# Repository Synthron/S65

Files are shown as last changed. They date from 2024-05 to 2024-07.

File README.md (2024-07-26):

# S65xx Computer System

Yet another 8bit Retro Computer

Completely bloated, overkill and fully hackable!

## ToDo

- [x] Finish Hardware
- Software
  - [ ] WozMon
    - [x] Implement Serial IO
    - [x] Implement Input Buffer
    - [ ] extended for block write
  - [ ] Kernel Functions
    - [ ] General SysCalls
    - [ ] Hardware Drivers
  - [x] RAM-Kernel
  - [x] Basic
  - [x] EhBasic
  - [ ] File System
  - [ ] Operating System
- Hardware
  - [ ] order PCBs
  - [ ] order parts
  - [ ] solder together

## Hardware

- Modules
  - [x] Backplane Bus
  - [x] CPU
  - [x] ROM
  - [x] RAM
  - [x] Bank/IRQ
  - [x] LCD/IRQ
  - [x] SIO
  - [x] PIO
  - [x] User Ports
  - [x] IDE
  - [x] Simple-IDE
  - [x] CF
  - [x] SID
  - [x] Addr + RTC + Clock
  - [x] Prototyping Board
  - [x] LPT Interface
  - [x] MyCPU Graphics Unit Interface

## Software Brainstorm

- EhBasic
  - maybe Microsoft Basic? See Ben Eater
    - both in different banks
- WozMon Main Boot
- Serial Program Bootloader
- File System (FAT?)
- DOS-Like UI

boot routine:

- selftest
  - RAM Check
  - ROM Check + version
- Load Kernel functions to RAM
- Start Monitor

## Memory Map

General:

| Start | End  | Usage | Size |
|---|---|---|---|
| 0000  | 7FFF | RAM | 32.768 |
| 8000  | BEFF | RAM Banked | 16.128 |
| BF00  | BFFF | IO Space | 256 |
| C000  | FFFF | ROM Banked | 16.384 |

IO Space:

| Start | End  | Usage |Size|
|---|---|---|----|
| BF00  | BF07 | Bank & IRQ | 8  |
| BF08  | BF0F | TPI IDE | 8  |
| BF10  | BF12 | LPT | 2  |
| BF13  | BF14 | --- (LPT2) | 2  |
| BF14  | BF16 | MyCPU VGA | 3  |
| BF17  | BF1B | --- | 5  |
| BF1C  | BF1F | PIA LEDs | 4  |
| BF20  | BF2F | VIA 1 LCD IRQ | 16 |
| BF30  | BF3F | VIA 2 | 16 |
| BF40  | BF4F | VIA 3 | 16 |
| BF50  | BF53 | ACIA 1 | 4  |
| BF54  | BF57 | ACIA 2 | 4  |
| BF58  | BF5B | --- (ACIA 3)  | 4  |
| BF5C  | BF5F | --- (ACIA 4)  | 4  |
| BF60  | BF7F | SID 8580 | 32 |
| BF80  | BF87 | Simple IDE | 8  |
| BF88  | BF8F | CF Card | 8  |
| BF90  | BF9F | RTC | 16 |
| BFA0  | BFFF | --- | 96 |

## Interrupts

The TPI Chip for the memory banks also functions as a priority interrupt controller, providing 5 seperate interrupt lines.  
IRQ_0 is further divided into 8 lines for communication modules, giving an overall of 14 available IRQ-Lines.  

These are currently used as follows:

- IRQ -> TPI
  - IRQ_0 -> VIA0
    - IRQ_0.0 -> ACIA0
    - IRQ_0.1 -> ACIA1
    - IRQ_0.2 -> ACIA2
    - IRQ_0.3 -> ACIA3
    - IRQ_0.4 -> RTC
    - IRQ_0.5 -> ---
    - IRQ_0.6 -> ---
    - IRQ_0.7 -> ---
  - IRQ_1 -> VIA1
  - IRQ_2 -> VIA2
  - IRQ_3 -> ---
  - IRQ_4 -> ---
- NMI -> ---

Note that the NMI is connected to a push button on the bus board.

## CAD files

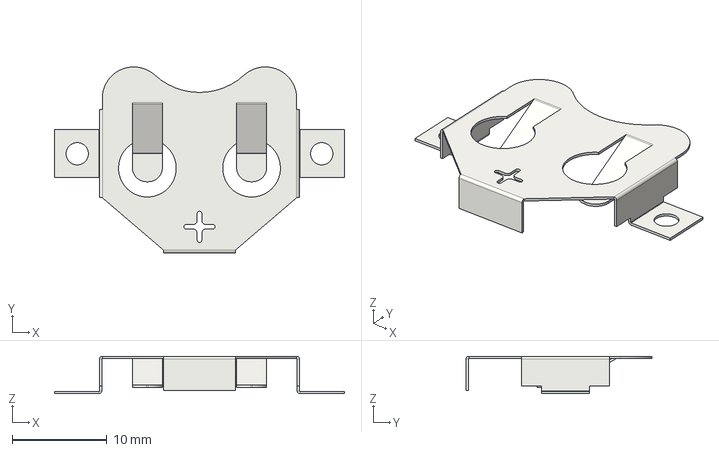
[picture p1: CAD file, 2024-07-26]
Hardware/modules/Address_Decode/BatteryHolder_Keystone_3002_1x2032.step
30.7 x 19.7 x 3.96 mm

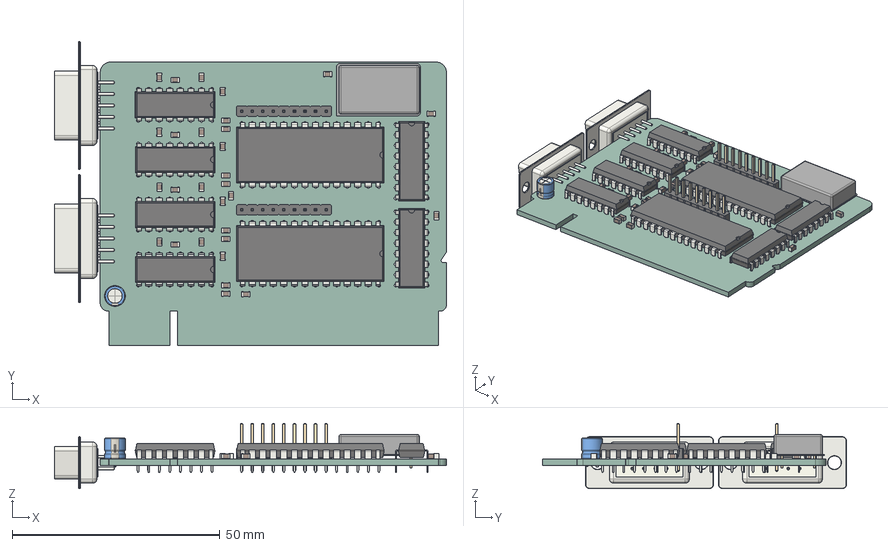
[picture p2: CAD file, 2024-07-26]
Hardware/modules/Bus_Card/modules_3d/ACIA2.step
94.3 x 73.1 x 15.7 mm
DIP-16_W7.62mm x 6
C_0805_2012Metric x 29
DSUB-9_Male_Vertical_P2.77x2.84mm x 2
DIP-28_W15.24mm x 2
Oscillator_DIP-14
CP_Radial_D50mm_P250mm
PinHeader_1x09_P254mm_Vertical x 2
ACIA2_PCB

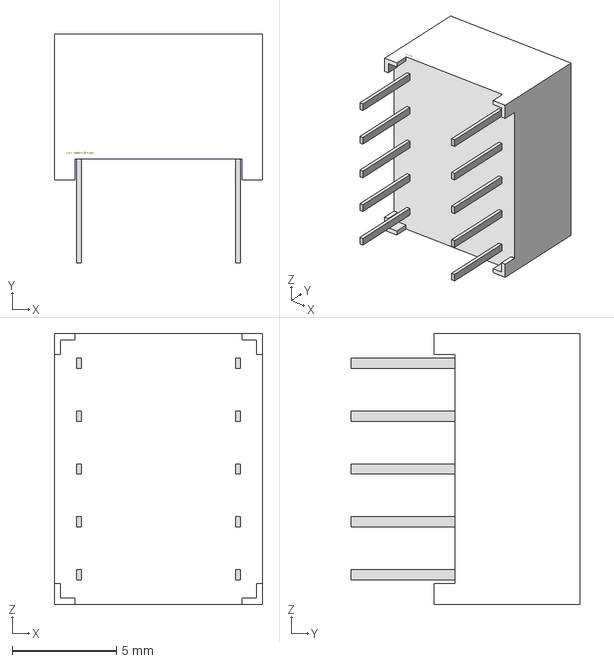
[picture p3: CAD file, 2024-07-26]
Hardware/modules/Bus_Card/Sx39-1xxxxx.step
10.0 x 11.0 x 13.0 mm

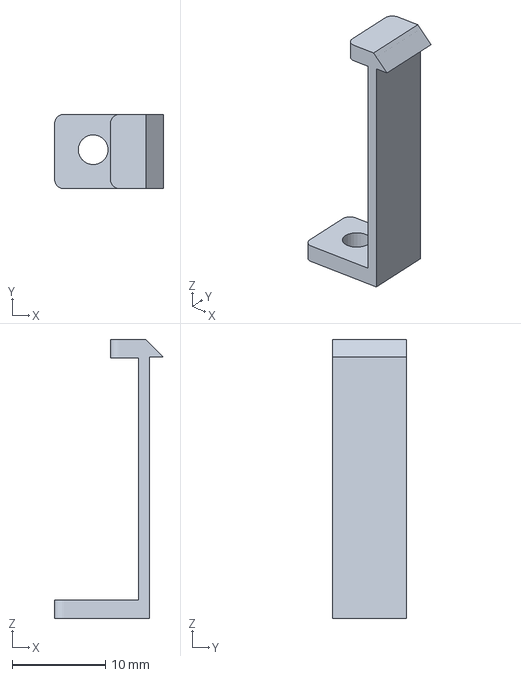
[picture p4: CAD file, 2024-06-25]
Hardware/PCB-Clamp/clamp-Clamp.3mf
11.7 x 8.00 x 30.0 mm

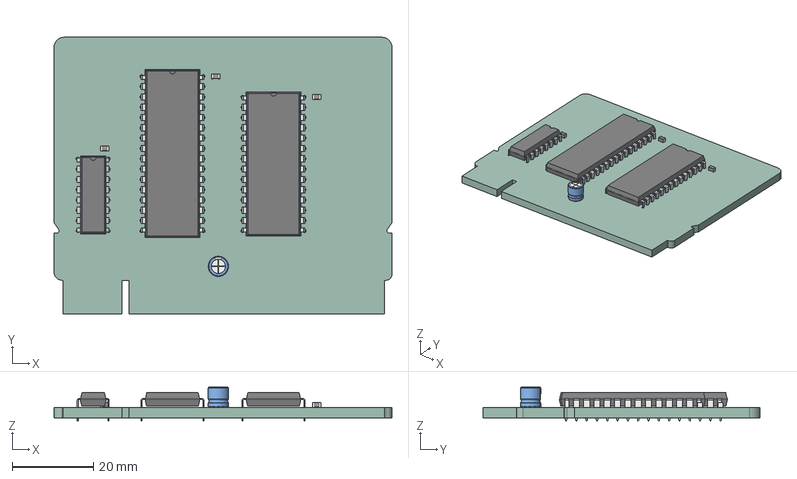
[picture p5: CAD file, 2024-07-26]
Hardware/modules/Bus_Card/modules_3d/RAM.step
83.3 x 68.2 x 8.30 mm
C_0805_2012Metric x 3
DIP-32_W15.24mm
DIP-28_W15.24mm
DIP-16_W7.62mm
CP_Radial_D50mm_P250mm
RAM_PCB

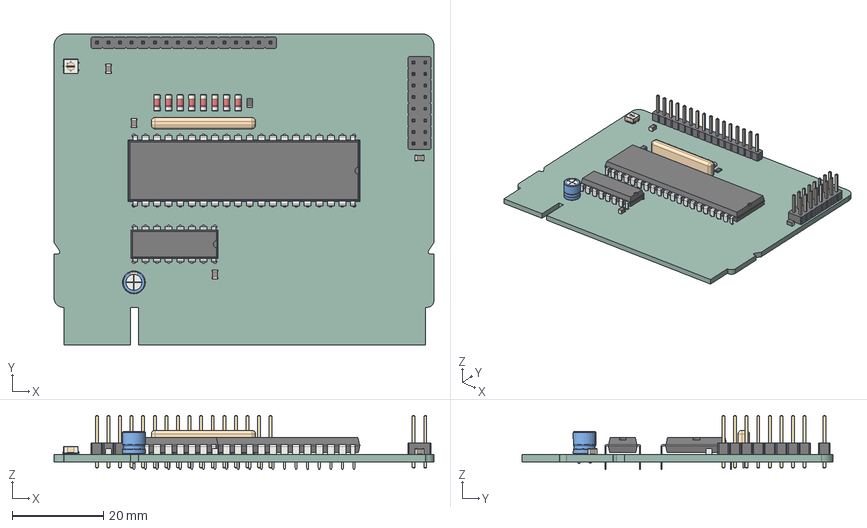
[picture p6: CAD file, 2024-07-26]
Hardware/modules/Bus_Card/modules_3d/LCD_IRQ.step
83.3 x 68.2 x 11.8 mm
Potentiometer_Bourns_3314J_Vertical
R_0805_2012Metric
D_MiniMELF_Standard x 8
C_0805_2012Metric x 4
PinHeader_2x08_P254mm_Vertical
DIP-40_W15.24mm
CP_Radial_D50mm_P250mm
PinHeader_1x16_P254mm_Vertical
DIP-16_W7.62mm
R_Array_SIP9
LCD_IRQ_PCB

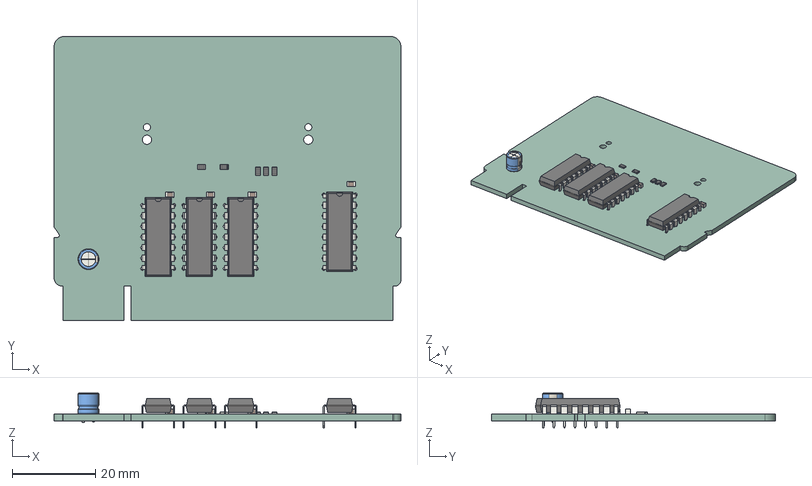
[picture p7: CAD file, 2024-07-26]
Hardware/modules/Bus_Card/modules_3d/CF.step
83.3 x 68.2 x 8.30 mm
R_0805_2012Metric x 5
C_0805_2012Metric x 4
DIP-14_W7.62mm x 3
DIP-16_W7.62mm
CP_Radial_D50mm_P250mm
CF_PCB

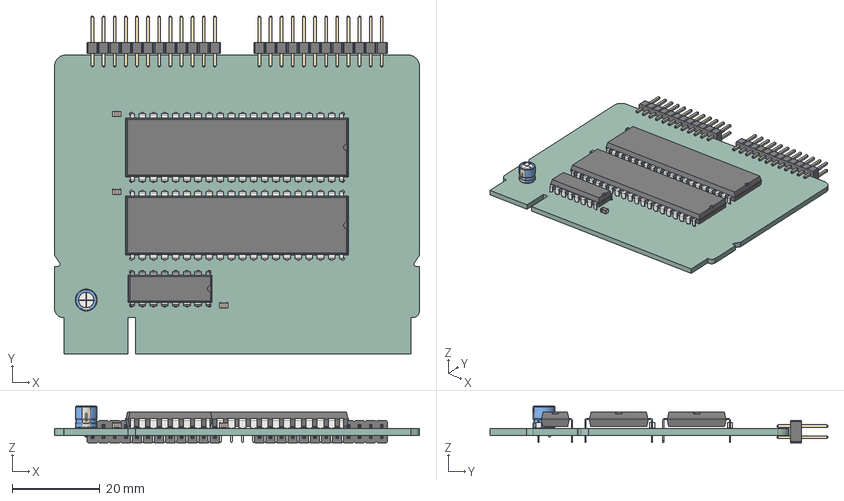
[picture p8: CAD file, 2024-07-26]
Hardware/modules/Bus_Card/modules_3d/VIAs.step
83.3 x 77.1 x 8.37 mm
C_0805_2012Metric x 3
DIP-40_W15.24mm x 2
DIP-16_W7.62mm
CP_Radial_D50mm_P250mm
PinHeader_2x12_P254mm_Vertical x 2
VIAs_PCB

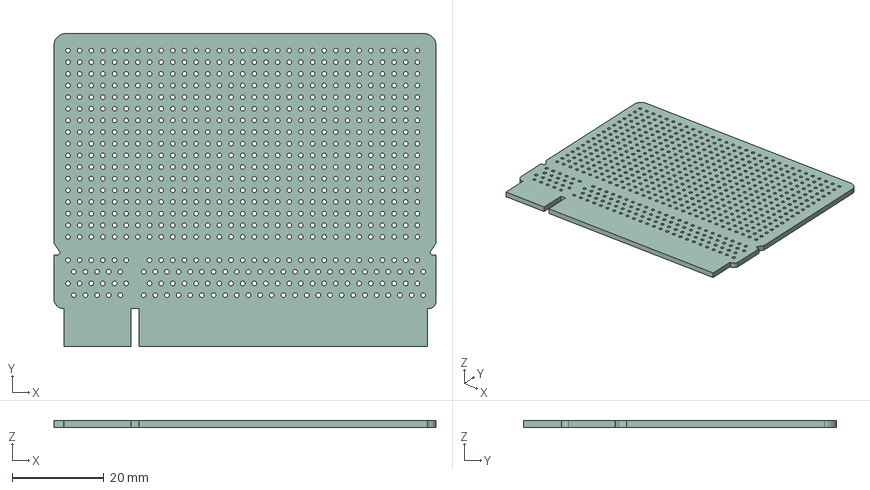
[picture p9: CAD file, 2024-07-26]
Hardware/modules/Bus_Card/modules_3d/Proto.step
83.3 x 68.2 x 1.61 mm

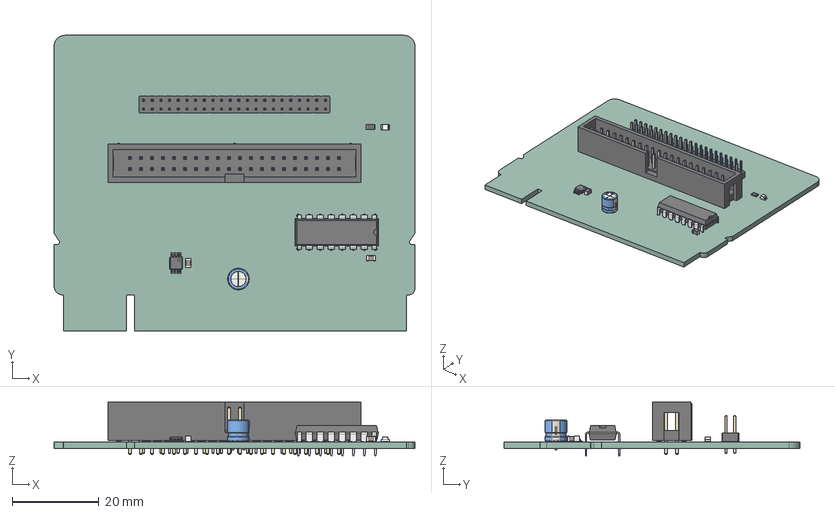
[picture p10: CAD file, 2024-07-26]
Hardware/modules/Bus_Card/modules_3d/IDE-Simple.step
83.3 x 68.2 x 12.4 mm
IDC_Header_2x20_P254mm_Vertical
TSSOP_8_3x3mm_P065mm
LED_0805_2012Metric
PinHeader_2x22_P200mm_Vertical
C_0805_2012Metric x 2
CP_Radial_D50mm_P250mm
DIP-16_W7.62mm
R_0805_2012Metric
IDE-Simple_PCB

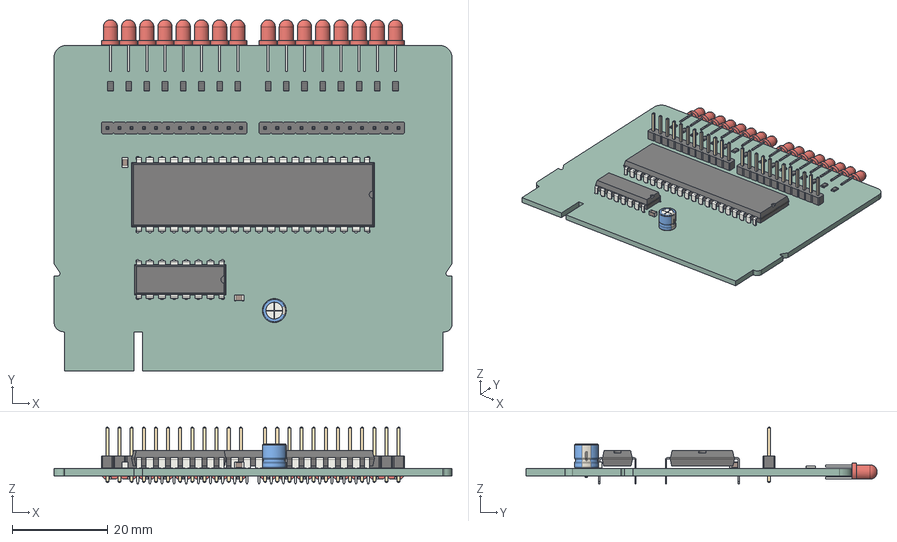
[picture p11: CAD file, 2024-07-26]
Hardware/modules/Bus_Card/modules_3d/PIA_LED.step
83.3 x 73.6 x 11.8 mm
R_0805_2012Metric x 16
C_0805_2012Metric x 2
PinHeader_1x12_P254mm_Vertical x 2
DIP-40_W15.24mm
DIP-16_W7.62mm
CP_Radial_D50mm_P250mm
LED_D3.0mm x 16
PIA_LED_PCB

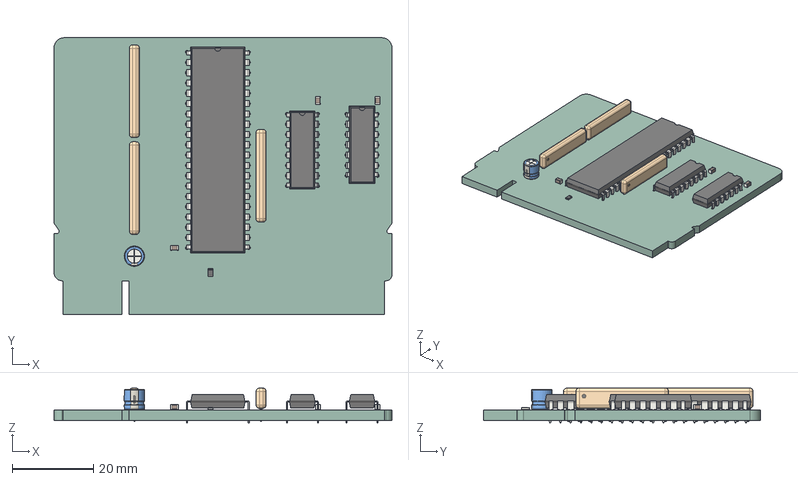
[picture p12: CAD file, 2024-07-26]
Hardware/modules/Bus_Card/modules_3d/Bank_IRQ.step
83.3 x 68.2 x 8.60 mm
R_0805_2012Metric
R_Array_SIP9 x 3
C_0805_2012Metric x 3
DIP-40_W15.24mm
DIP-16_W7.62mm
DIP-14_W7.62mm
CP_Radial_D50mm_P250mm
Bank_IRQ_PCB

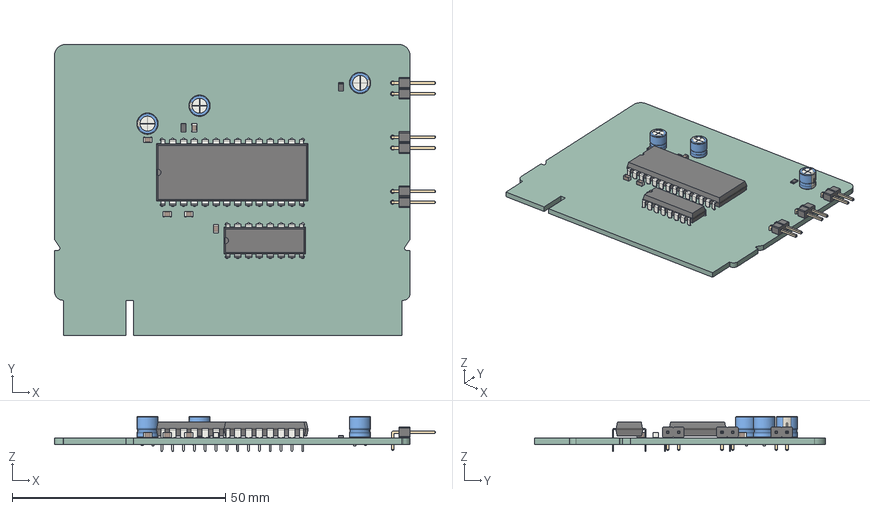
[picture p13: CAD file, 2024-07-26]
Hardware/modules/Bus_Card/modules_3d/SID.step
89.3 x 68.2 x 8.30 mm
R_0805_2012Metric x 2
C_0805_2012Metric x 5
DIP-28_W15.24mm
CP_Radial_D50mm_P250mm x 3
DIP-16_W7.62mm
PinHeader_1x02_P254mm_Horizontal x 3
SID_PCB

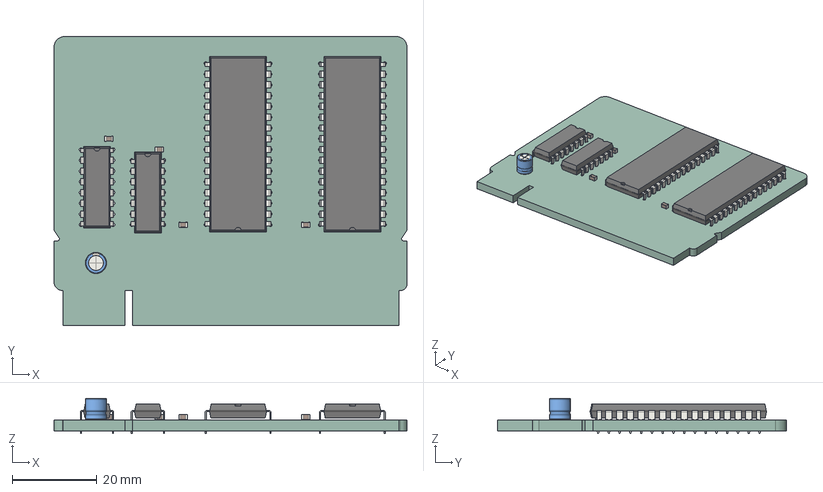
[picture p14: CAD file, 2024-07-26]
Hardware/modules/Bus_Card/modules_3d/ROM.step
83.3 x 68.2 x 8.30 mm
DIP-16_W7.62mm
C_0805_2012Metric x 4
DIP-32_W15.24mm x 2
CP_Radial_D50mm_P250mm
DIP-14_W7.62mm
ROM_PCB

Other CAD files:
Hardware/modules/Bus_Card/clamp-Clamp.stp
Hardware/PCB-Clamp/clamp.FCStd
Hardware/modules/Bus_Card/modules_3d/LPT.step
Hardware/modules/Bus_Card/modules_3d/CPU.step

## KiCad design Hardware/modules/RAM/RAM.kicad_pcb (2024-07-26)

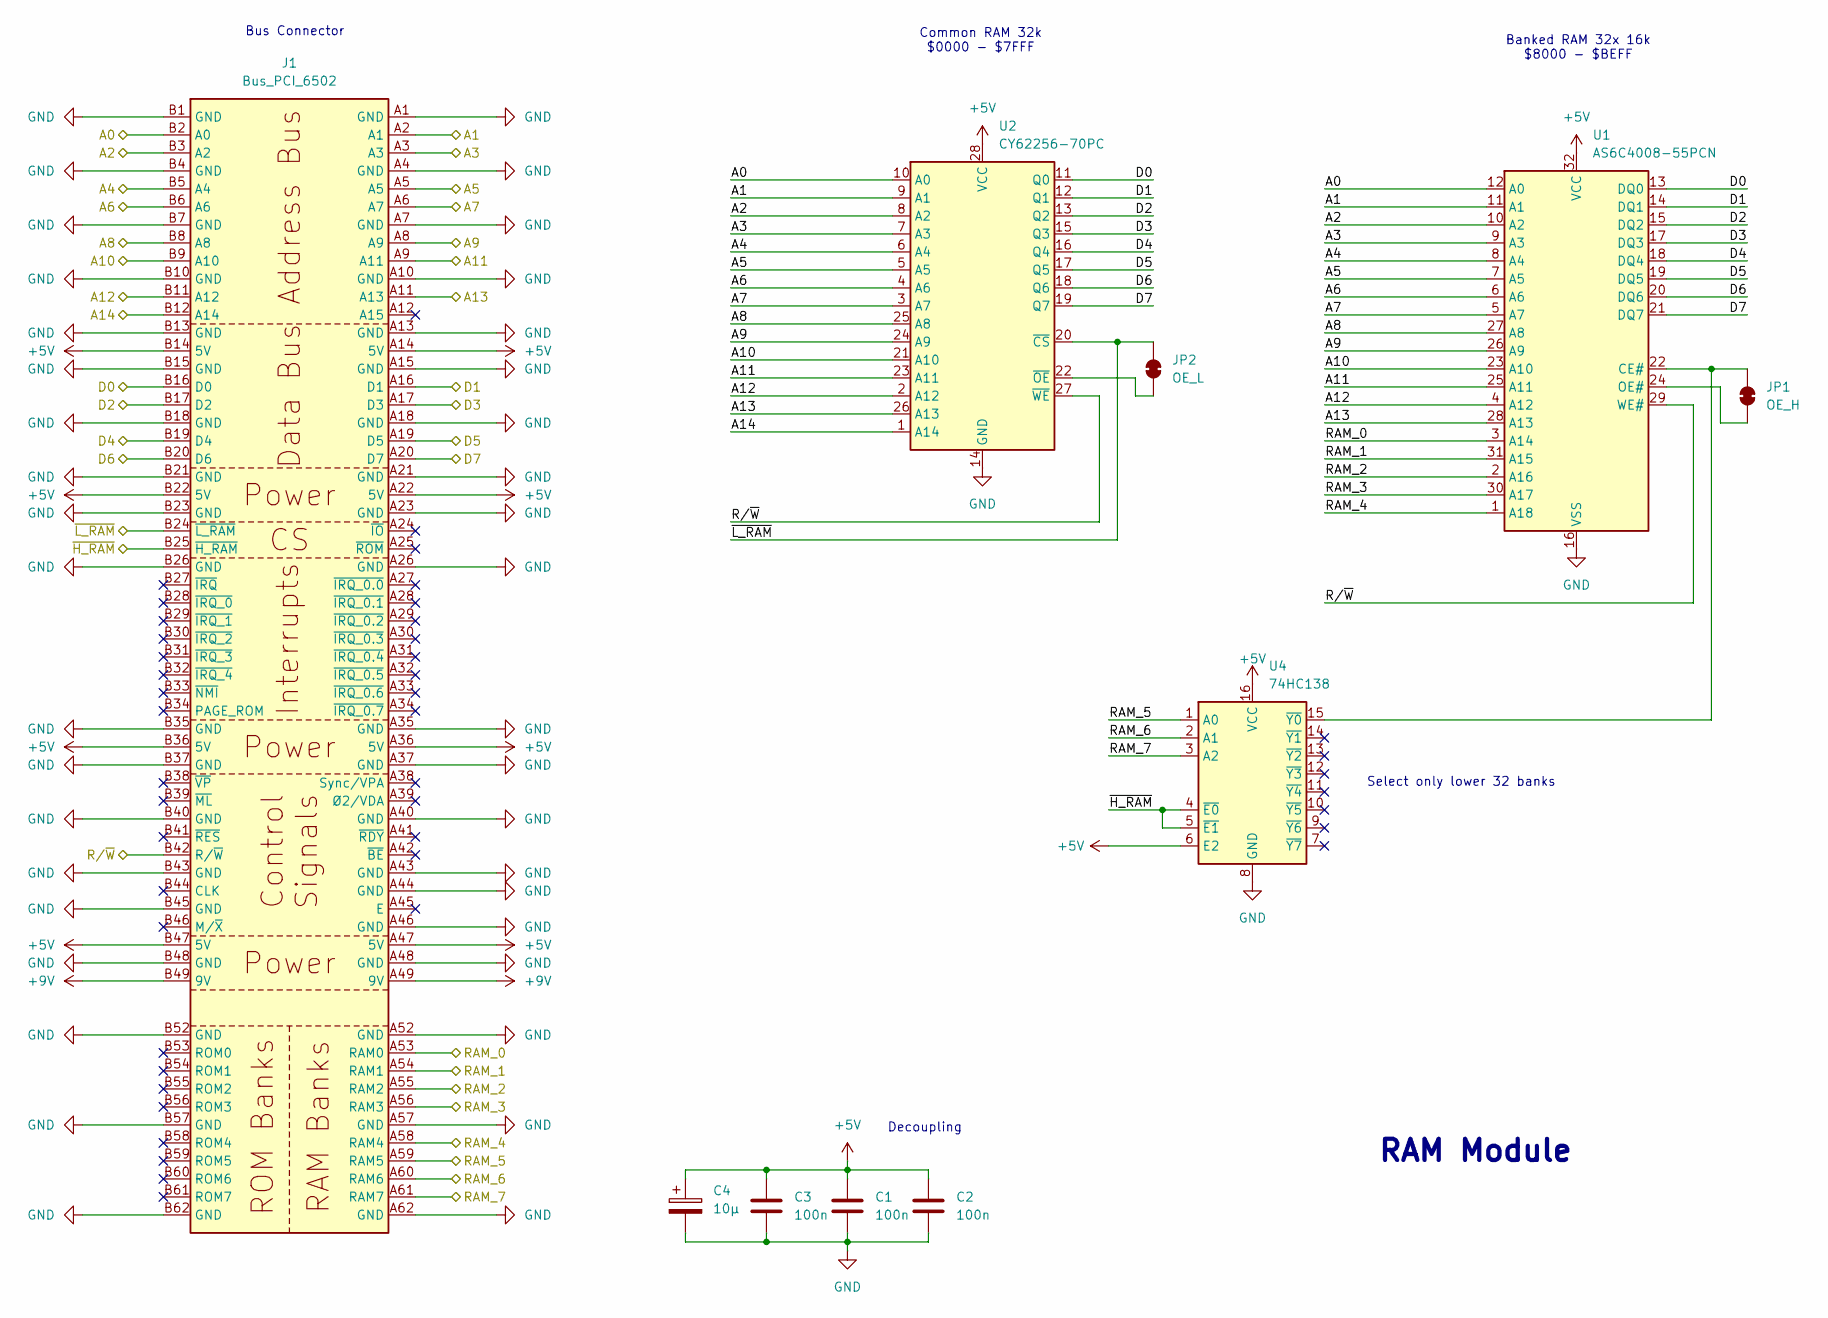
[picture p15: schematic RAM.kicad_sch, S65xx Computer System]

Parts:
C1, C2, C3: 100n; C_0805_2012Metric
C4: 10µ; CP_Radial_D5.0mm_P2.50mm
J1: Bus_PCI_6502; BUS_PCI
JP1: OE_H; SolderJumper-2_P1.3mm_Bridged_RoundedPad1.0x1.5mm
JP2: OE_L; SolderJumper-2_P1.3mm_Bridged_RoundedPad1.0x1.5mm
U1: AS6C4008-55PCN; DIP-32_W15.24mm
U2: CY62256-70PC; DIP-28_W15.24mm
U4: 74HC138; DIP-16_W7.62mm

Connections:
+5V: C1.1, C2.1, C3.1, C4.1, J1.A14 (5V), J1.A22 (5V), J1.A36 (5V), J1.A47 (5V), J1.B14 (5V), J1.B22 (5V), J1.B36 (5V), J1.B47 (5V), U1.32 (VCC), U2.28 (VCC), U4.6 (E2), U4.16 (VCC)
+9V: J1.A49 (9V), J1.B49 (9V)
/A0: J1.B2 (A0), U1.12 (A0), U2.10 (A0)
/A1: J1.A2 (A1), U1.11 (A1), U2.9 (A1)
/A2: J1.B3 (A2), U1.10 (A2), U2.8 (A2)
/A3: J1.A3, U1.9 (A3), U2.7 (A3)
/A4: J1.B5 (A4), U1.8 (A4), U2.6 (A4)
/A5: J1.A5, U1.7 (A5), U2.5 (A5)
/A6: J1.B6 (A6), U1.6 (A6), U2.4 (A6)
/A7: J1.A6 (A7), U1.5 (A7), U2.3 (A7)
/A8: J1.B8 (A8), U1.27 (A8), U2.25 (A8)
/A9: J1.A8 (A9), U1.26 (A9), U2.24 (A9)
/A10: J1.B9 (A10), U1.23 (A10), U2.21 (A10)
/A11: J1.A9 (A11), U1.25 (A11), U2.23 (A11)
/A12: J1.B11 (A12), U1.4 (A12), U2.2 (A12)
/A13: J1.A11 (A13), U1.28 (A13), U2.26 (A13)
/A14: J1.B12 (A14), U2.1 (A14)
/D0: J1.B16 (D0), U1.13 (DQ0), U2.11 (Q0)
/D1: J1.A16 (D1), U1.14 (DQ1), U2.12 (Q1)
/D2: J1.B17 (D2), U1.15 (DQ2), U2.13 (Q2)
/D3: J1.A17 (D3), U1.17 (DQ3), U2.15 (Q3)
/D4: J1.B19 (D4), U1.18 (DQ4), U2.16 (Q4)
/D5: J1.A19 (D5), U1.19 (DQ5), U2.17 (Q5)
/D6: J1.B20 (D6), U1.20 (DQ6), U2.18 (Q6)
/D7: J1.A20 (D7), U1.21 (DQ7), U2.19 (Q7)
/RAM_0: J1.A53 (RAM0), U1.3 (A14)
/RAM_1: J1.A54 (RAM1), U1.31 (A15)
/RAM_2: J1.A55 (RAM2), U1.2 (A16)
/RAM_3: J1.A56 (RAM3), U1.30 (A17)
/RAM_4: J1.A58 (RAM4), U1.1 (A18)
/RAM_5: J1.A59 (RAM5), U4.1 (A0)
/RAM_6: J1.A60 (RAM6), U4.2 (A1)
/RAM_7: J1.A61 (RAM7), U4.3 (A2)
/R/~W: J1.B42 (R/~W), U1.29 (WE#), U2.27 (~WE)
/~H_RAM: J1.B25 (~H_RAM), U4.4 (~E0), U4.5 (~E1)
/~L_RAM: J1.B24 (~L_RAM), JP2.2 (B), U2.20 (~CS)
GND: C1.2, C2.2, C3.2, C4.2, J1.A1 (GND), J1.A4 (GND), J1.A7 (GND), J1.A10 (GND), J1.A13 (GND), J1.A15 (GND), J1.A18 (GND), J1.A21 (GND), J1.A23 (GND), J1.A26 (GND), J1.A35 (GND), J1.A37 (GND), J1.A40 (GND), J1.A43 (GND), J1.A44 (GND), J1.A46 (GND), J1.A48 (GND), J1.A52 (GND), J1.A57 (GND), J1.A62 (GND), J1.B1 (GND), J1.B4 (GND), J1.B7 (GND), J1.B10 (GND), J1.B13 (GND), J1.B15 (GND), J1.B18 (GND), J1.B21 (GND), J1.B23 (GND), J1.B26 (GND), J1.B35 (GND), J1.B37 (GND), J1.B40 (GND), J1.B43 (GND), J1.B45 (GND), J1.B48 (GND), J1.B52 (GND), J1.B57 (GND), J1.B62 (GND), U1.16 (VSS), U2.14 (GND), U4.8 (GND)
unnamed: JP1.1 (A), U1.24 (OE#)
unnamed: JP1.2 (B), U1.22 (CE#), U4.15 (~Y0)
unnamed: JP2.1 (A), U2.22 (~OE)

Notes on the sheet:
Common RAM 32k $0000 - $7FFF
RAM Module
Bus Connector
Select only lower 32 banks
Decoupling
Banked RAM 32x 16k $8000 - $BEFF

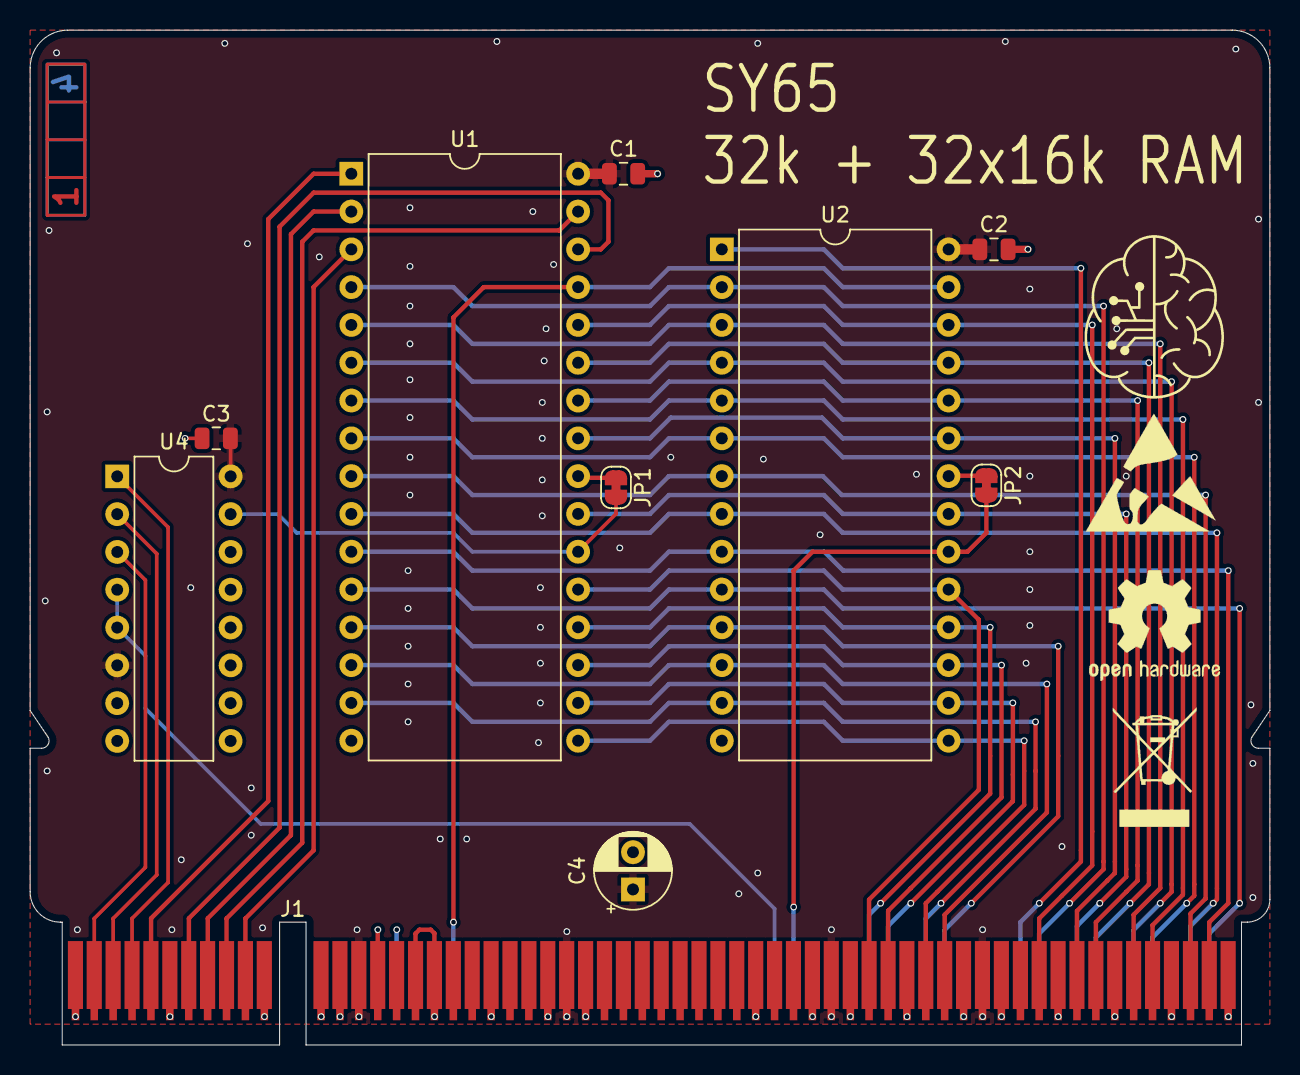
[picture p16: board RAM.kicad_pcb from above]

Board: 4 copper layers, 83.3 x 68.2 mm, 11 parts (1 on the bottom side), 40 nets.

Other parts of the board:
Ref**: Val**; ladder_4

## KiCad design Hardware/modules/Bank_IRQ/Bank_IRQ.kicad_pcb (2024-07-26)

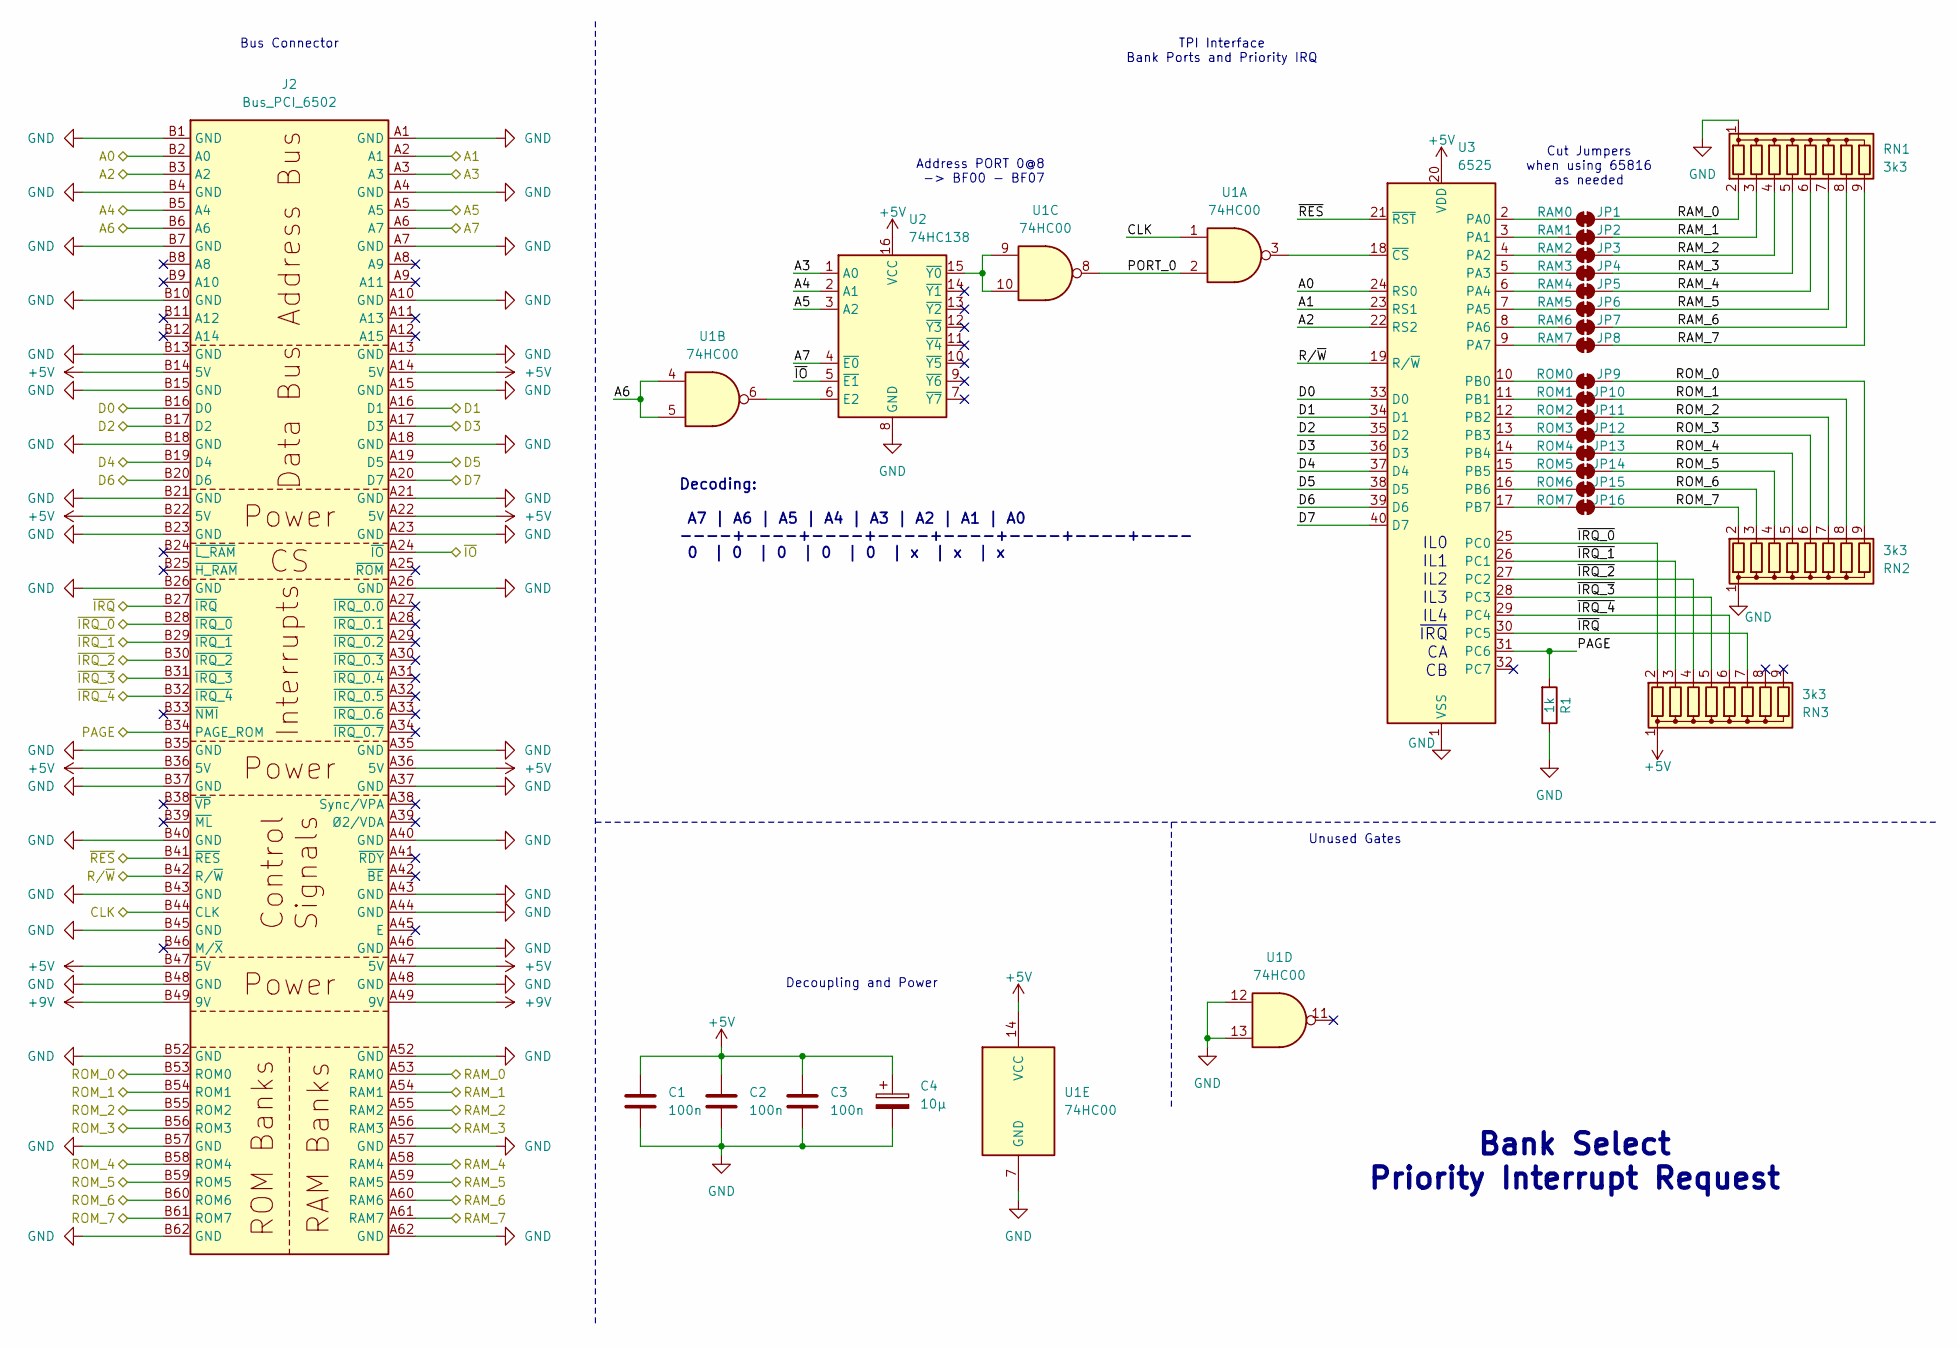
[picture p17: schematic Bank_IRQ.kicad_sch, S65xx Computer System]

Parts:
C1, C2, C3: 100n; C_0805_2012Metric
C4: 10µ; CP_Radial_D5.0mm_P2.50mm
J2: Bus_PCI_6502; BUS_PCI
JP1: RAM0; SolderJumper-2_P1.3mm_Bridged_RoundedPad1.0x1.5mm
JP2: RAM1; SolderJumper-2_P1.3mm_Bridged_RoundedPad1.0x1.5mm
JP3: RAM2; SolderJumper-2_P1.3mm_Bridged_RoundedPad1.0x1.5mm
JP4: RAM3; SolderJumper-2_P1.3mm_Bridged_RoundedPad1.0x1.5mm
JP5: RAM4; SolderJumper-2_P1.3mm_Bridged_RoundedPad1.0x1.5mm
JP6: RAM5; SolderJumper-2_P1.3mm_Bridged_RoundedPad1.0x1.5mm
JP7: RAM6; SolderJumper-2_P1.3mm_Bridged_RoundedPad1.0x1.5mm
JP8: RAM7; SolderJumper-2_P1.3mm_Bridged_RoundedPad1.0x1.5mm
JP9: ROM0; SolderJumper-2_P1.3mm_Bridged_RoundedPad1.0x1.5mm
JP10: ROM1; SolderJumper-2_P1.3mm_Bridged_RoundedPad1.0x1.5mm
JP11: ROM2; SolderJumper-2_P1.3mm_Bridged_RoundedPad1.0x1.5mm
JP12: ROM3; SolderJumper-2_P1.3mm_Bridged_RoundedPad1.0x1.5mm
JP13: ROM4; SolderJumper-2_P1.3mm_Bridged_RoundedPad1.0x1.5mm
JP14: ROM5; SolderJumper-2_P1.3mm_Bridged_RoundedPad1.0x1.5mm
JP15: ROM6; SolderJumper-2_P1.3mm_Bridged_RoundedPad1.0x1.5mm
JP16: ROM7; SolderJumper-2_P1.3mm_Bridged_RoundedPad1.0x1.5mm
R1: 1k; R_0805_2012Metric
RN1, RN2, RN3: 3k3; R_Array_SIP9
U1: 74HC00; DIP-14_W7.62mm_LongPads
U2: 74HC138; DIP-16_W7.62mm_LongPads
U3: 6525; DIP-40_W15.24mm

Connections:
+5V: C1.1, C2.1, C3.1, C4.1, J2.A14 (5V), J2.A22 (5V), J2.A36 (5V), J2.A47 (5V), J2.B14 (5V), J2.B22 (5V), J2.B36 (5V), J2.B47 (5V), RN3.1 (common), U1.14 (VCC), U2.16 (VCC), U3.20 (VDD)
+9V: J2.A49 (9V), J2.B49 (9V)
/A0: J2.B2 (A0), U3.24 (RS0)
/A1: J2.A2 (A1), U3.23 (RS1)
/A2: J2.B3 (A2), U3.22 (RS2)
/A3: J2.A3, U2.1 (A0)
/A4: J2.B5 (A4), U2.2 (A1)
/A5: J2.A5, U2.3 (A2)
/A6: J2.B6 (A6), U1.4, U1.5
/A7: J2.A6 (A7), U2.4 (~E0)
/CLK: J2.B44 (CLK), U1.1
/D0: J2.B16 (D0), U3.33 (D0)
/D1: J2.A16 (D1), U3.34 (D1)
/D2: J2.B17 (D2), U3.35 (D2)
/D3: J2.A17 (D3), U3.36 (D3)
/D4: J2.B19 (D4), U3.37 (D4)
/D5: J2.A19 (D5), U3.38 (D5)
/D6: J2.B20 (D6), U3.39 (D6)
/D7: J2.A20 (D7), U3.40 (D7)
/PAGE: J2.B34 (PAGE_ROM), R1.2, U3.31 (PC6)
/PORT_0: U1.2, U1.8
/RAM_0: J2.A53 (RAM0), JP1.2 (B), RN1.2 (R1)
/RAM_1: J2.A54 (RAM1), JP2.2 (B), RN1.3 (R2)
/RAM_2: J2.A55 (RAM2), JP3.2 (B), RN1.4 (R3)
/RAM_3: J2.A56 (RAM3), JP4.2 (B), RN1.5 (R4)
/RAM_4: J2.A58 (RAM4), JP5.2 (B), RN1.6 (R5)
/RAM_5: J2.A59 (RAM5), JP6.2 (B), RN1.7 (R6)
/RAM_6: J2.A60 (RAM6), JP7.2 (B), RN1.8 (R7)
/RAM_7: J2.A61 (RAM7), JP8.2 (B), RN1.9 (R8)
/ROM_0: J2.B53 (ROM0), JP9.2 (B), RN2.9 (R8)
/ROM_1: J2.B54 (ROM1), JP10.2 (B), RN2.8 (R7)
/ROM_2: J2.B55 (ROM2), JP11.2 (B), RN2.7 (R6)
/ROM_3: J2.B56 (ROM3), JP12.2 (B), RN2.6 (R5)
/ROM_4: J2.B58 (ROM4), JP13.2 (B), RN2.5 (R4)
/ROM_5: J2.B59 (ROM5), JP14.2 (B), RN2.4 (R3)
/ROM_6: J2.B60 (ROM6), JP15.2 (B), RN2.3 (R2)
/ROM_7: J2.B61 (ROM7), JP16.2 (B), RN2.2 (R1)
/R/~W: J2.B42 (R/~W), U3.19 (R/~W)
/~IO: J2.A24 (~IO), U2.5 (~E1)
/~IRQ_0: J2.B28 (~IRQ_0), RN3.2 (R1), U3.25 (PC0)
/~IRQ_1: J2.B29 (~IRQ_1), RN3.3 (R2), U3.26 (PC1)
/~IRQ_2: J2.B30 (~IRQ_2), RN3.4 (R3), U3.27 (PC2)
/~IRQ_3: J2.B31 (~IRQ_3), RN3.5 (R4), U3.28 (PC3)
/~IRQ_4: J2.B32 (~IRQ_4), RN3.6 (R5), U3.29 (PC4)
/~IRQ: J2.B27 (~IRQ), RN3.7 (R6), U3.30 (PC5)
/~RES: J2.B41 (~RES), U3.21 (~RST)
GND: C1.2, C2.2, C3.2, C4.2, J2.A1 (GND), J2.A4 (GND), J2.A7 (GND), J2.A10 (GND), J2.A13 (GND), J2.A15 (GND), J2.A18 (GND), J2.A21 (GND), J2.A23 (GND), J2.A26 (GND), J2.A35 (GND), J2.A37 (GND), J2.A40 (GND), J2.A43 (GND), J2.A44 (GND), J2.A46 (GND), J2.A48 (GND), J2.A52 (GND), J2.A57 (GND), J2.A62 (GND), J2.B1 (GND), J2.B4 (GND), J2.B7 (GND), J2.B10 (GND), J2.B13 (GND), J2.B15 (GND), J2.B18 (GND), J2.B21 (GND), J2.B23 (GND), J2.B26 (GND), J2.B35 (GND), J2.B37 (GND), J2.B40 (GND), J2.B43 (GND), J2.B45 (GND), J2.B48 (GND), J2.B52 (GND), J2.B57 (GND), J2.B62 (GND), R1.1, RN1.1 (common), RN2.1 (common), U1.7 (GND), U1.12, U1.13, U2.8 (GND), U3.1 (VSS)
unnamed: JP1.1 (A), U3.2 (PA0)
unnamed: JP2.1 (A), U3.3 (PA1)
unnamed: JP3.1 (A), U3.4 (PA2)
unnamed: JP4.1 (A), U3.5 (PA3)
unnamed: JP5.1 (A), U3.6 (PA4)
unnamed: JP6.1 (A), U3.7 (PA5)
unnamed: JP7.1 (A), U3.8 (PA6)
unnamed: JP8.1 (A), U3.9 (PA7)
unnamed: JP9.1 (A), U3.10 (PB0)
unnamed: JP10.1 (A), U3.11 (PB1)
unnamed: JP11.1 (A), U3.12 (PB2)
unnamed: JP12.1 (A), U3.13 (PB3)
unnamed: JP13.1 (A), U3.14 (PB4)
unnamed: JP14.1 (A), U3.15 (PB5)
unnamed: JP15.1 (A), U3.16 (PB6)
unnamed: JP16.1 (A), U3.17 (PB7)
unnamed: U1.6, U2.6 (E2)
unnamed: U1.9, U1.10, U2.15 (~Y0)
unnamed: U1.3, U3.18 (~CS)

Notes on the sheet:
Decoding: A7 | A6 | A5 | A4 | A3 | A2 | A1 | A0 ----+----+----+----+----+----+----+---- 0 | 0 | 0 | 0 | 0 | x | x | x
Bus Connector
Cut Jumpers when using 65816 as needed
Bank Select Priority Interrupt Request
TPI Interface Bank Ports and Priority IRQ
Decoupling and Power
Unused Gates
Address PORT 0@8 -> BF00 - BF07
IL0 IL1 IL2 IL3 IL4 ~{IRQ} CA CB

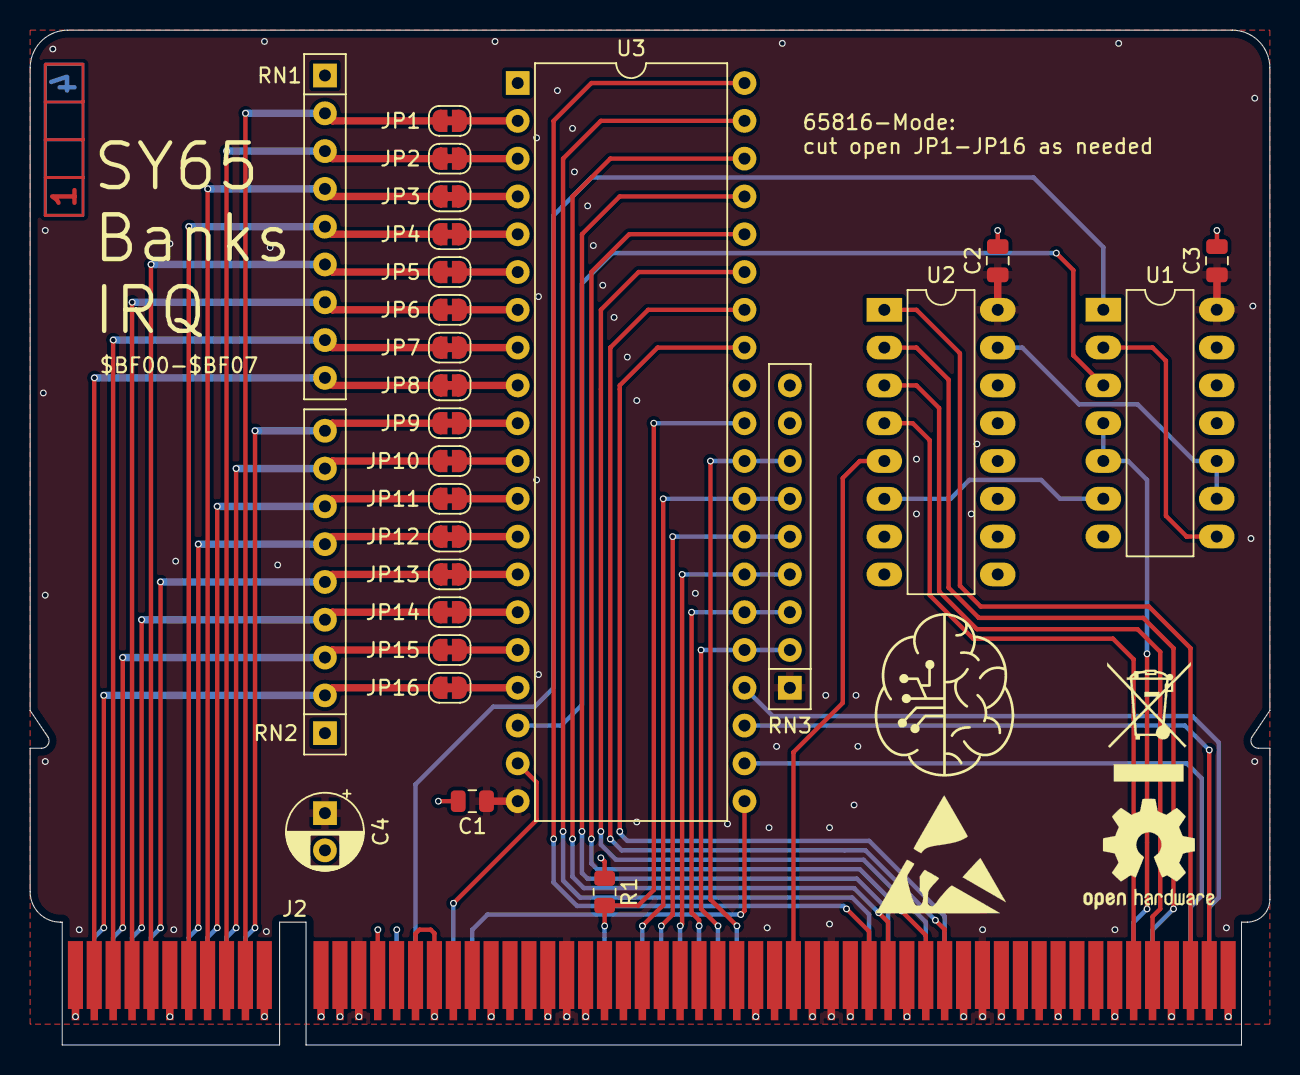
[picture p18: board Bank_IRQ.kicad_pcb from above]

Board: 4 copper layers, 83.3 x 68.2 mm, 29 parts (1 on the bottom side), 66 nets.

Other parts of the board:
Ref**: Val**; ladder_4

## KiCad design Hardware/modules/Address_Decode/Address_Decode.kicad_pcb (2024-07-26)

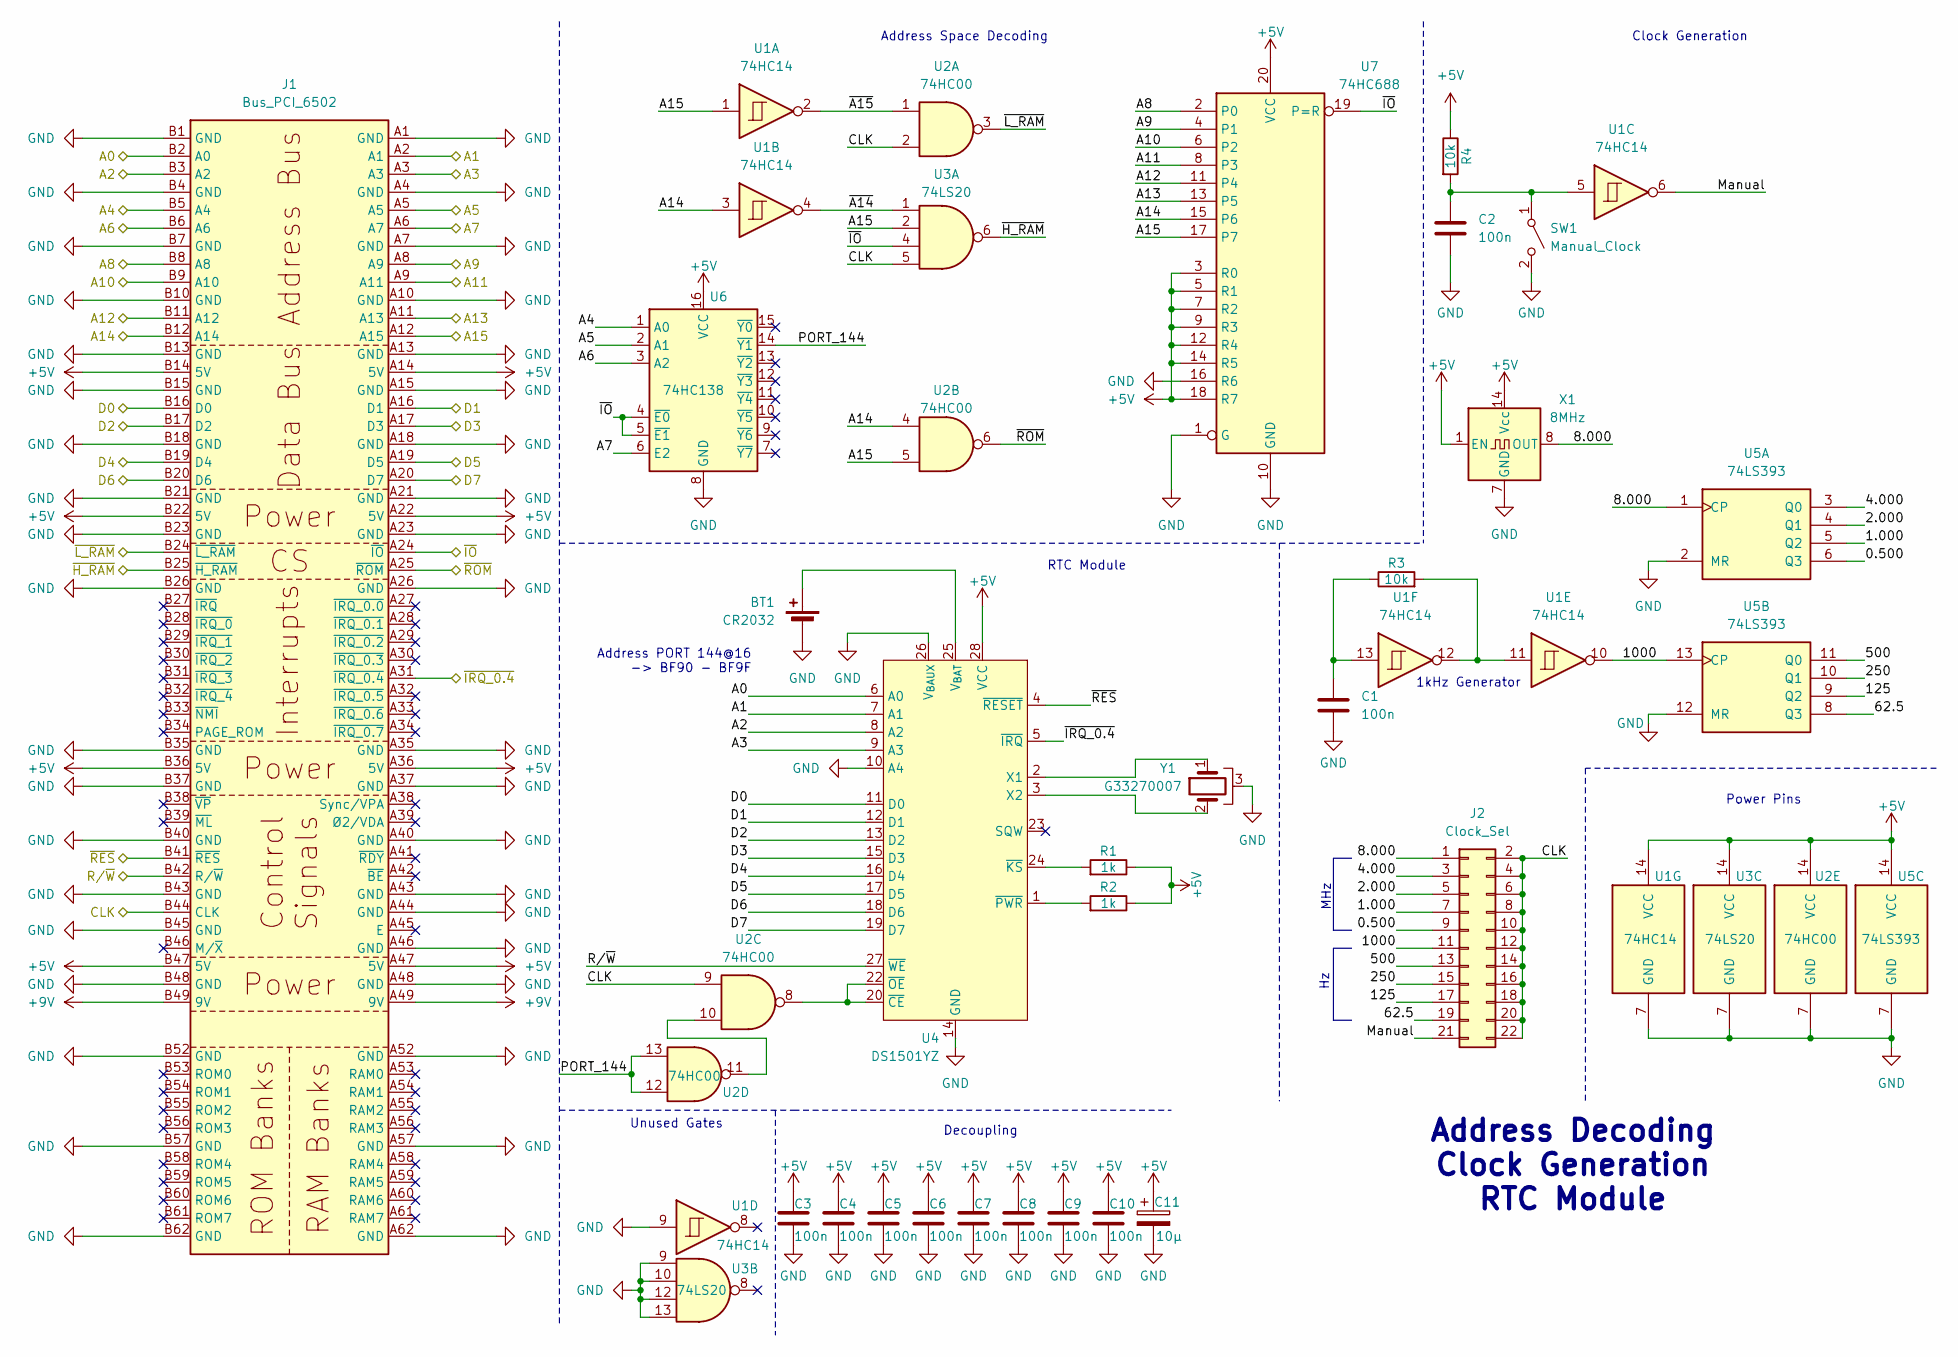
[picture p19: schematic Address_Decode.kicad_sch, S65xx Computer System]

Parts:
BT1: CR2032; BatteryHolder_Keystone_3002_1x2032
C1, C2, C3, C4, C5, C6, C7, C8, C9, C10: 100n; C_0805_2012Metric
C11: 10µ; CP_Radial_D5.0mm_P2.50mm
J1: Bus_PCI_6502; BUS_PCI
J2: Clock_Sel; PinHeader_2x11_P2.54mm_Horizontal
R1, R2: 1k; R_0805_2012Metric
R3, R4: 10k; R_0805_2012Metric
SW1: Manual_Clock; SPST_Edge
U1: 74HC14; DIP-14_W7.62mm_LongPads
U2: 74HC00; DIP-14_W7.62mm_LongPads
U3: 74LS20; DIP-14_W7.62mm_LongPads
U4: DS1501YZ; SOP-28_8.4x18.16mm_P1.27mm
U5: 74LS393; DIP-14_W7.62mm_LongPads
U6: 74HC138; DIP-16_W7.62mm_LongPads
U7: 74HC688; DIP-20_W7.62mm_LongPads
X1: 8MHz; Oscillator_DIP-14
Y1: G33270007; Crystal_SMD_FrontierElectronics_FM206

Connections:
+5V: C3.1, C4.1, C5.1, C6.1, C7.1, C8.1, C9.1, C10.1, C11.1, J1.A14 (5V), J1.A22 (5V), J1.A36 (5V), J1.A47 (5V), J1.B14 (5V), J1.B22 (5V), J1.B36 (5V), J1.B47 (5V), R1.1, R2.1, R4.1, U1.14 (VCC), U2.14 (VCC), U3.14 (VCC), U4.28 (VCC), U5.14 (VCC), U6.16 (VCC), U7.3 (R0), U7.5 (R1), U7.7 (R2), U7.9 (R3), U7.12 (R4), U7.14 (R5), U7.18 (R7), U7.20 (VCC), X1.1 (EN), X1.14 (Vcc)
+9V: J1.A49 (9V), J1.B49 (9V)
/0.500: J2.9, U5.6 (Q3)
/1.000: J2.7, U5.5 (Q2)
/2.000: J2.5, U5.4 (Q1)
/4.000: J2.3, U5.3 (Q0)
/8.000: J2.1, U5.1 (CP), X1.8 (OUT)
/62.5: J2.19, U5.8 (Q3)
/125: J2.17, U5.9 (Q2)
/250: J2.15, U5.10 (Q1)
/500: J2.13, U5.11 (Q0)
/1000: J2.11, U1.10, U5.13 (CP)
/A0: J1.B2 (A0), U4.6 (A0)
/A1: J1.A2 (A1), U4.7 (A1)
/A2: J1.B3 (A2), U4.8 (A2)
/A3: J1.A3, U4.9 (A3)
/A4: J1.B5 (A4), U6.1 (A0)
/A5: J1.A5, U6.2 (A1)
/A6: J1.B6 (A6), U6.3 (A2)
/A7: J1.A6 (A7), U6.6 (E2)
/A8: J1.B8 (A8), U7.2 (P0)
/A9: J1.A8 (A9), U7.4 (P1)
/A10: J1.B9 (A10), U7.6 (P2)
/A11: J1.A9 (A11), U7.8 (P3)
/A12: J1.B11 (A12), U7.11 (P4)
/A13: J1.A11 (A13), U7.13 (P5)
/A14: J1.B12 (A14), U1.3, U2.4, U7.15 (P6)
/A15: J1.A12 (A15), U1.1, U2.5, U3.2, U7.17 (P7)
/CLK: J1.B44 (CLK), J2.2, J2.4, J2.6, J2.8, J2.10, J2.12, J2.14, J2.16, J2.18, J2.20, J2.22, U2.2, U2.9, U3.5
/D0: J1.B16 (D0), U4.11 (D0)
/D1: J1.A16 (D1), U4.12 (D1)
/D2: J1.B17 (D2), U4.13 (D2)
/D3: J1.A17 (D3), U4.15 (D3)
/D4: J1.B19 (D4), U4.16 (D4)
/D5: J1.A19 (D5), U4.17 (D5)
/D6: J1.B20 (D6), U4.18 (D6)
/D7: J1.A20 (D7), U4.19 (D7)
/Manual: J2.21, U1.6
/PORT_144: U2.12, U2.13, U6.14 (~Y1)
/R/~W: J1.B42 (R/~W), U4.27 (~WE)
/~A14: U1.4, U3.1
/~A15: U1.2, U2.1
/~H_RAM: J1.B25 (~H_RAM), U3.6
/~IO: J1.A24 (~IO), U3.4, U6.4 (~E0), U6.5 (~E1), U7.19 (P=R)
/~IRQ_0.4: J1.A31 (~IRQ_0.4), U4.5 (~IRQ)
/~L_RAM: J1.B24 (~L_RAM), U2.3
/~RES: J1.B41 (~RES), U4.4 (~RESET)
/~ROM: J1.A25 (~ROM), U2.6
GND: BT1.2 (-), C1.2, C2.2, C3.2, C4.2, C5.2, C6.2, C7.2, C8.2, C9.2, C10.2, C11.2, J1.A1 (GND), J1.A4 (GND), J1.A7 (GND), J1.A10 (GND), J1.A13 (GND), J1.A15 (GND), J1.A18 (GND), J1.A21 (GND), J1.A23 (GND), J1.A26 (GND), J1.A35 (GND), J1.A37 (GND), J1.A40 (GND), J1.A43 (GND), J1.A44 (GND), J1.A46 (GND), J1.A48 (GND), J1.A52 (GND), J1.A57 (GND), J1.A62 (GND), J1.B1 (GND), J1.B4 (GND), J1.B7 (GND), J1.B10 (GND), J1.B13 (GND), J1.B15 (GND), J1.B18 (GND), J1.B21 (GND), J1.B23 (GND), J1.B26 (GND), J1.B35 (GND), J1.B37 (GND), J1.B40 (GND), J1.B43 (GND), J1.B45 (GND), J1.B48 (GND), J1.B52 (GND), J1.B57 (GND), J1.B62 (GND), SW1.2 (B), U1.7 (GND), U1.9, U2.7 (GND), U3.7 (GND), U3.9, U3.10, U3.12, U3.13, U4.10 (A4), U4.14 (GND), U4.21 (GND), U4.26 (V_{BAUX}), U5.2 (MR), U5.7 (GND), U5.12 (MR), U6.8 (GND), U7.1 (G), U7.10 (GND), U7.16 (R6), X1.7 (GND), Y1.3
unnamed: BT1.1 (+), U4.25 (V_{BAT})
unnamed: C1.1, R3.1, U1.13
unnamed: R3.2, U1.11, U1.12
unnamed: C2.1, R4.2, SW1.1 (A), U1.5
unnamed: U2.10, U2.11
unnamed: U4.2 (X1), Y1.1
unnamed: U4.3 (X2), Y1.2
unnamed: U2.8, U4.20 (~CE), U4.22 (~OE)
unnamed: R1.2, U4.24 (~KS)
unnamed: R2.2, U4.1 (~PWR)

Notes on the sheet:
Clock Generation
1kHz Generator
RTC Module
Address Decoding Clock Generation RTC Module
Power Pins
Address Space Decoding
MHz
Unused Gates
Address PORT 144@16 -> BF90 - BF9F
Decoupling

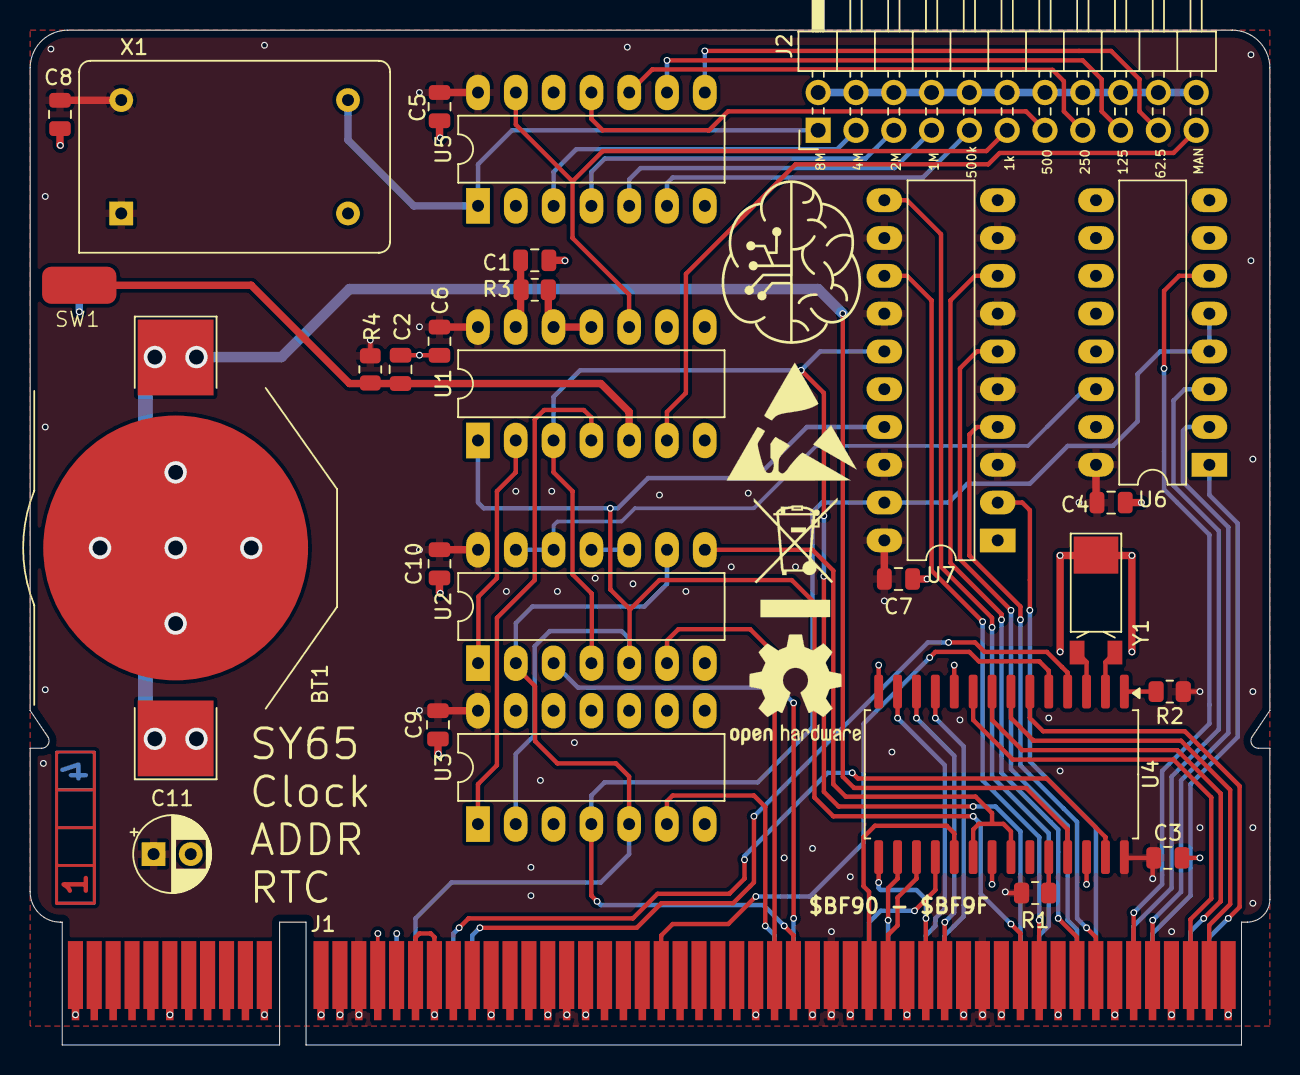
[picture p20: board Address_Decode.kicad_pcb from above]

Board: 4 copper layers, 83.3 x 68.2 mm, 29 parts (1 on the bottom side), 59 nets.

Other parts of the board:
Ref**: Val**; ladder_4

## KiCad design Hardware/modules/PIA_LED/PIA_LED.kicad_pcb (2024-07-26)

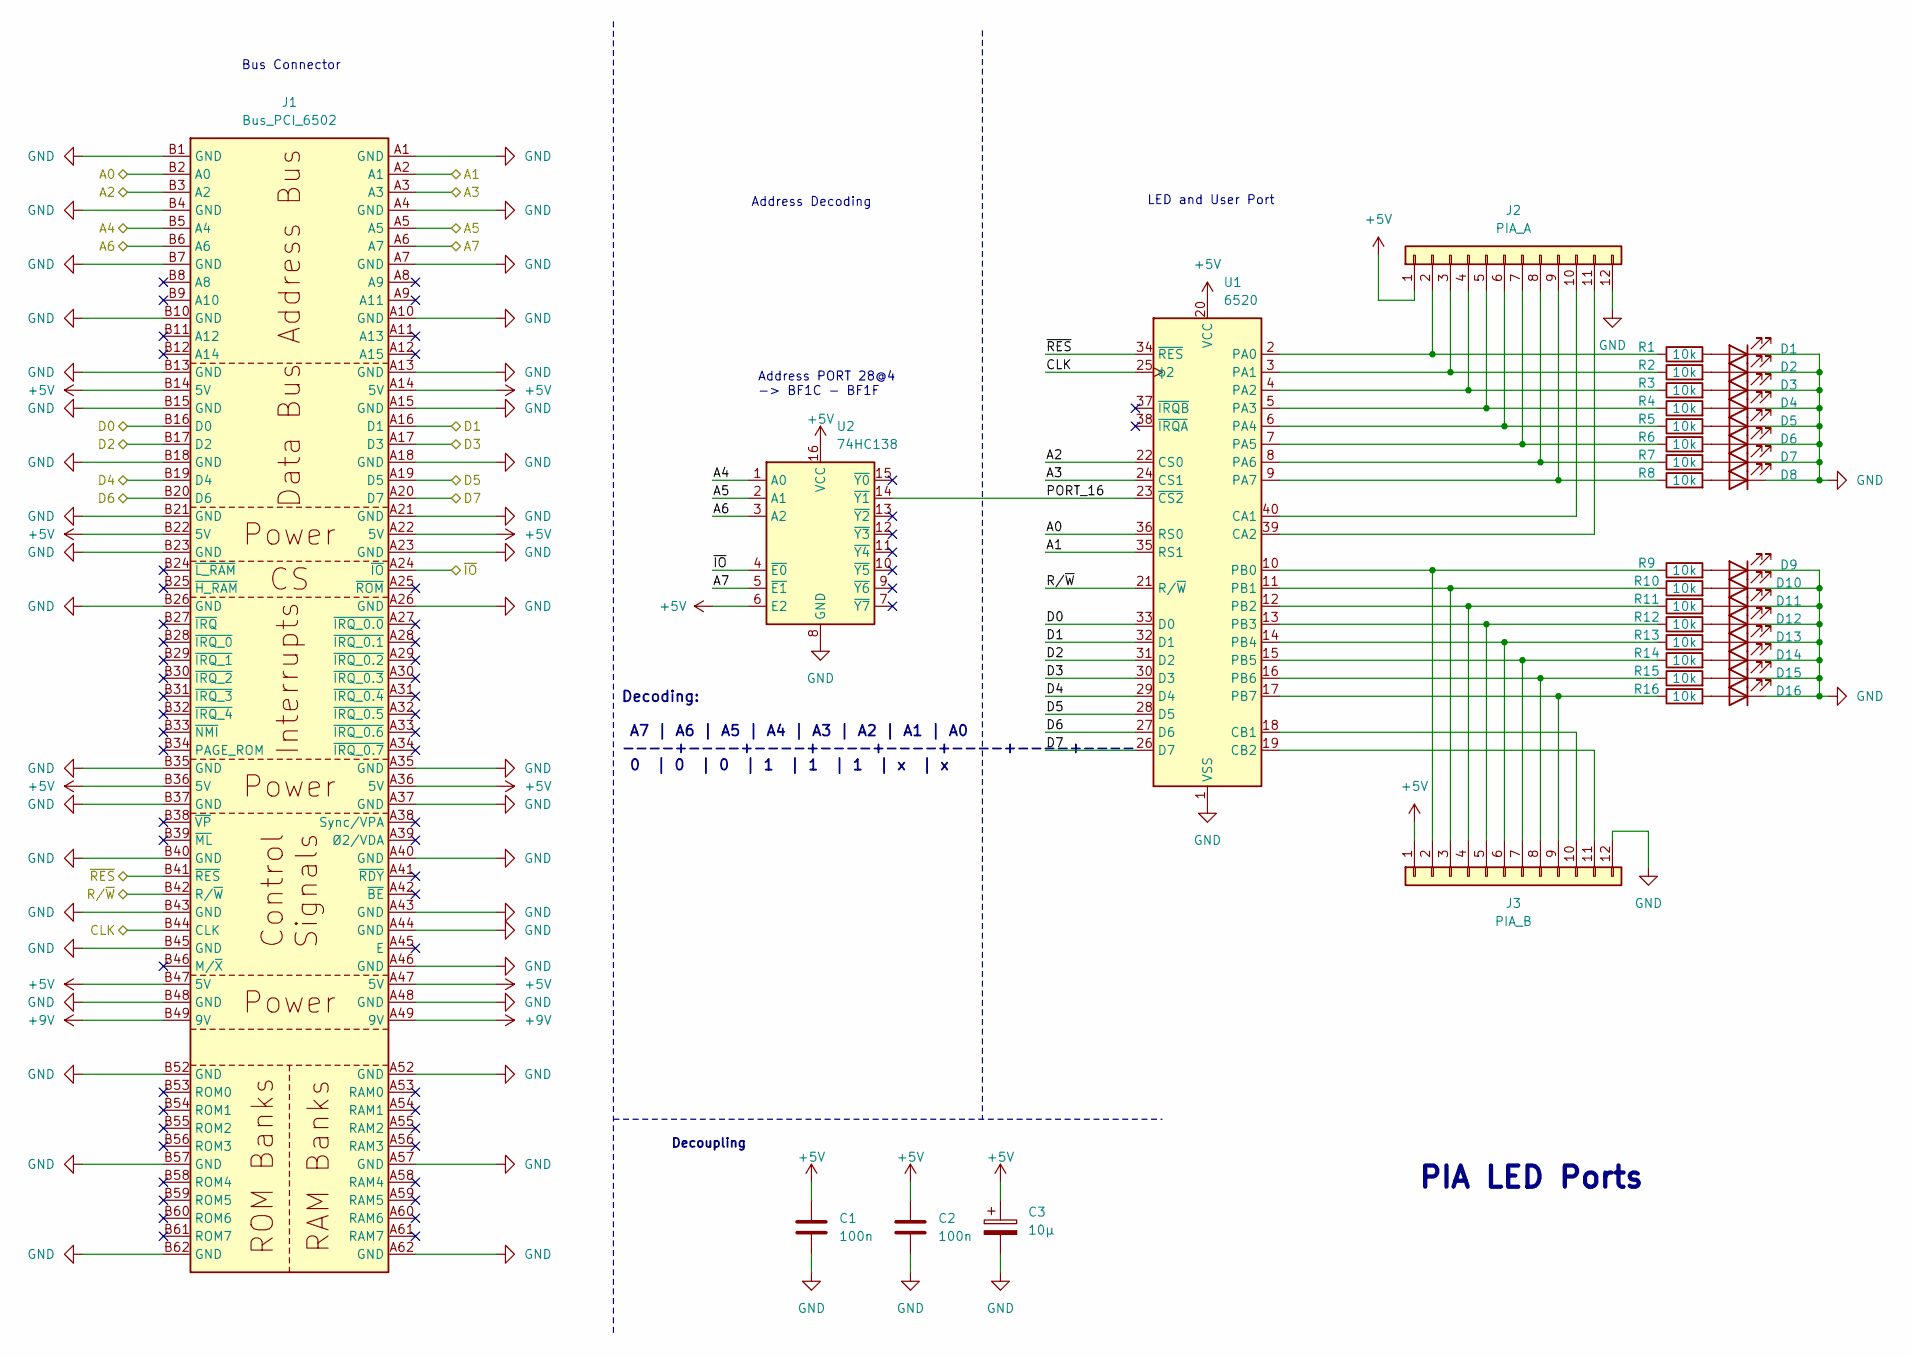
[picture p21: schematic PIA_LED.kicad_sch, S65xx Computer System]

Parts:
C1, C2: 100n; C_0805_2012Metric
C3: 10µ; CP_Radial_D5.0mm_P2.50mm
D1, D2, D3, D4, D5, D6, D7, D8, D9, D10, D11, D12, D13, D14, D15, D16: LED; SPST_Edge
J1: Bus_PCI_6502; BUS_PCI
J2: PIA_A; PinHeader_1x12_P2.54mm_Vertical
J3: PIA_B; PinHeader_1x12_P2.54mm_Vertical
R1, R2, R3, R4, R5, R6, R7, R8, R9, R10, R11, R12, R13, R14, R15, R16: 10k; R_0805_2012Metric
U1: 6520; DIP-40_W15.24mm
U2: 74HC138; DIP-16_W7.62mm_LongPads

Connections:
+5V: C1.1, C2.1, C3.1, J1.A14 (5V), J1.A22 (5V), J1.A36 (5V), J1.A47 (5V), J1.B14 (5V), J1.B22 (5V), J1.B36 (5V), J1.B47 (5V), J2.1, J3.1, U1.20 (VCC), U2.6 (E2), U2.16 (VCC)
+9V: J1.A49 (9V), J1.B49 (9V)
/A0: J1.B2 (A0), U1.36 (RS0)
/A1: J1.A2 (A1), U1.35 (RS1)
/A2: J1.B3 (A2), U1.22 (CS0)
/A3: J1.A3, U1.24 (CS1)
/A4: J1.B5 (A4), U2.1 (A0)
/A5: J1.A5, U2.2 (A1)
/A6: J1.B6 (A6), U2.3 (A2)
/A7: J1.A6 (A7), U2.5 (~E1)
/CLK: J1.B44 (CLK), U1.25 (ϕ2)
/D0: J1.B16 (D0), U1.33 (D0)
/D1: J1.A16 (D1), U1.32 (D1)
/D2: J1.B17 (D2), U1.31 (D2)
/D3: J1.A17 (D3), U1.30 (D3)
/D4: J1.B19 (D4), U1.29 (D4)
/D5: J1.A19 (D5), U1.28 (D5)
/D6: J1.B20 (D6), U1.27 (D6)
/D7: J1.A20 (D7), U1.26 (D7)
/PORT_16: U1.23 (~CS2), U2.14 (~Y1)
/R/~W: J1.B42 (R/~W), U1.21 (R/~W)
/~IO: J1.A24 (~IO), U2.4 (~E0)
/~RES: J1.B41 (~RES), U1.34 (~RES)
GND: C1.2, C2.2, C3.2, D1.1 (K), D2.1 (K), D3.1 (K), D4.1 (K), D5.1 (K), D6.1 (K), D7.1 (K), D8.1 (K), D9.1 (K), D10.1 (K), D11.1 (K), D12.1 (K), D13.1 (K), D14.1 (K), D15.1 (K), D16.1 (K), J1.A1 (GND), J1.A4 (GND), J1.A7 (GND), J1.A10 (GND), J1.A13 (GND), J1.A15 (GND), J1.A18 (GND), J1.A21 (GND), J1.A23 (GND), J1.A26 (GND), J1.A35 (GND), J1.A37 (GND), J1.A40 (GND), J1.A43 (GND), J1.A44 (GND), J1.A46 (GND), J1.A48 (GND), J1.A52 (GND), J1.A57 (GND), J1.A62 (GND), J1.B1 (GND), J1.B4 (GND), J1.B7 (GND), J1.B10 (GND), J1.B13 (GND), J1.B15 (GND), J1.B18 (GND), J1.B21 (GND), J1.B23 (GND), J1.B26 (GND), J1.B35 (GND), J1.B37 (GND), J1.B40 (GND), J1.B43 (GND), J1.B45 (GND), J1.B48 (GND), J1.B52 (GND), J1.B57 (GND), J1.B62 (GND), J2.12, J3.12, U1.1 (VSS), U2.8 (GND)
unnamed: D1.2 (A), R1.2
unnamed: D2.2 (A), R2.2
unnamed: D3.2 (A), R3.2
unnamed: D4.2 (A), R4.2
unnamed: D5.2 (A), R5.2
unnamed: D6.2 (A), R6.2
unnamed: D7.2 (A), R7.2
unnamed: D8.2 (A), R8.2
unnamed: D9.2 (A), R9.2
unnamed: D10.2 (A), R10.2
unnamed: D11.2 (A), R11.2
unnamed: D12.2 (A), R12.2
unnamed: D13.2 (A), R13.2
unnamed: D14.2 (A), R14.2
unnamed: D15.2 (A), R15.2
unnamed: D16.2 (A), R16.2
unnamed: J2.2, R1.1, U1.2 (PA0)
unnamed: J2.3, R2.1, U1.3 (PA1)
unnamed: J2.4, R3.1, U1.4 (PA2)
unnamed: J2.5, R4.1, U1.5 (PA3)
unnamed: J2.6, R5.1, U1.6 (PA4)
unnamed: J2.7, R6.1, U1.7 (PA5)
unnamed: J2.8, R7.1, U1.8 (PA6)
unnamed: J2.9, R8.1, U1.9 (PA7)
unnamed: J2.10, U1.40 (CA1)
unnamed: J2.11, U1.39 (CA2)
unnamed: J3.2, R9.1, U1.10 (PB0)
unnamed: J3.3, R10.1, U1.11 (PB1)
unnamed: J3.4, R11.1, U1.12 (PB2)
unnamed: J3.5, R12.1, U1.13 (PB3)
unnamed: J3.6, R13.1, U1.14 (PB4)
unnamed: J3.7, R14.1, U1.15 (PB5)
unnamed: J3.8, R15.1, U1.16 (PB6)
unnamed: J3.9, R16.1, U1.17 (PB7)
unnamed: J3.10, U1.18 (CB1)
unnamed: J3.11, U1.19 (CB2)

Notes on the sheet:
Decoding: A7 | A6 | A5 | A4 | A3 | A2 | A1 | A0 ----+----+----+----+----+----+----+---- 0 | 0 | 0 | 1 | 1 | 1 | x | x
PIA LED Ports
Address PORT 28@4 -> BF1C - BF1F
Address Decoding
Bus Connector
Decoupling
LED and User Port

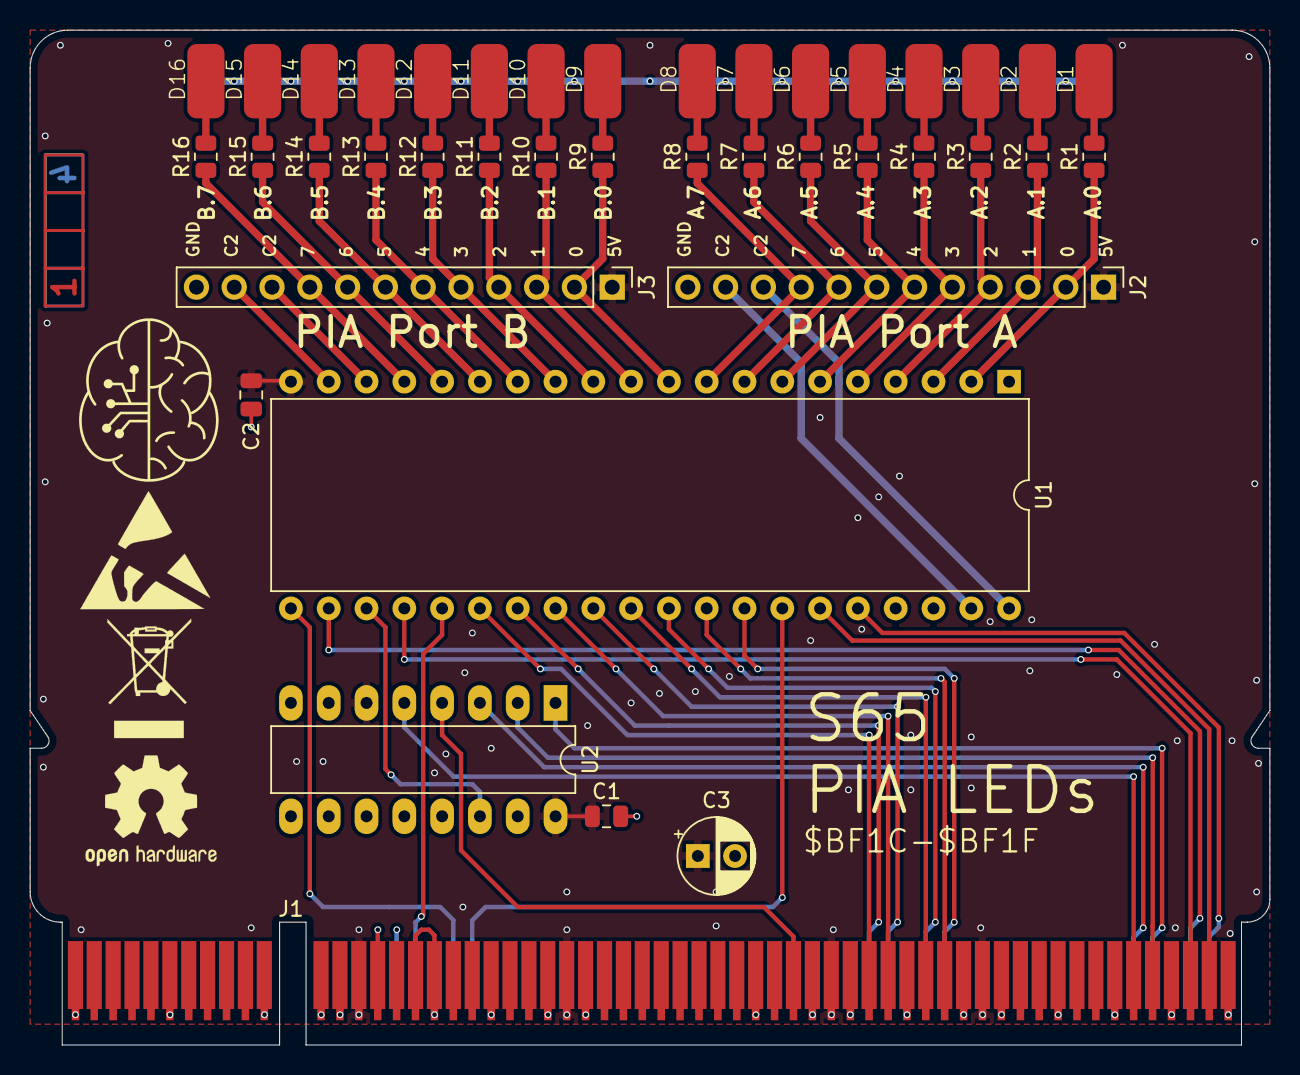
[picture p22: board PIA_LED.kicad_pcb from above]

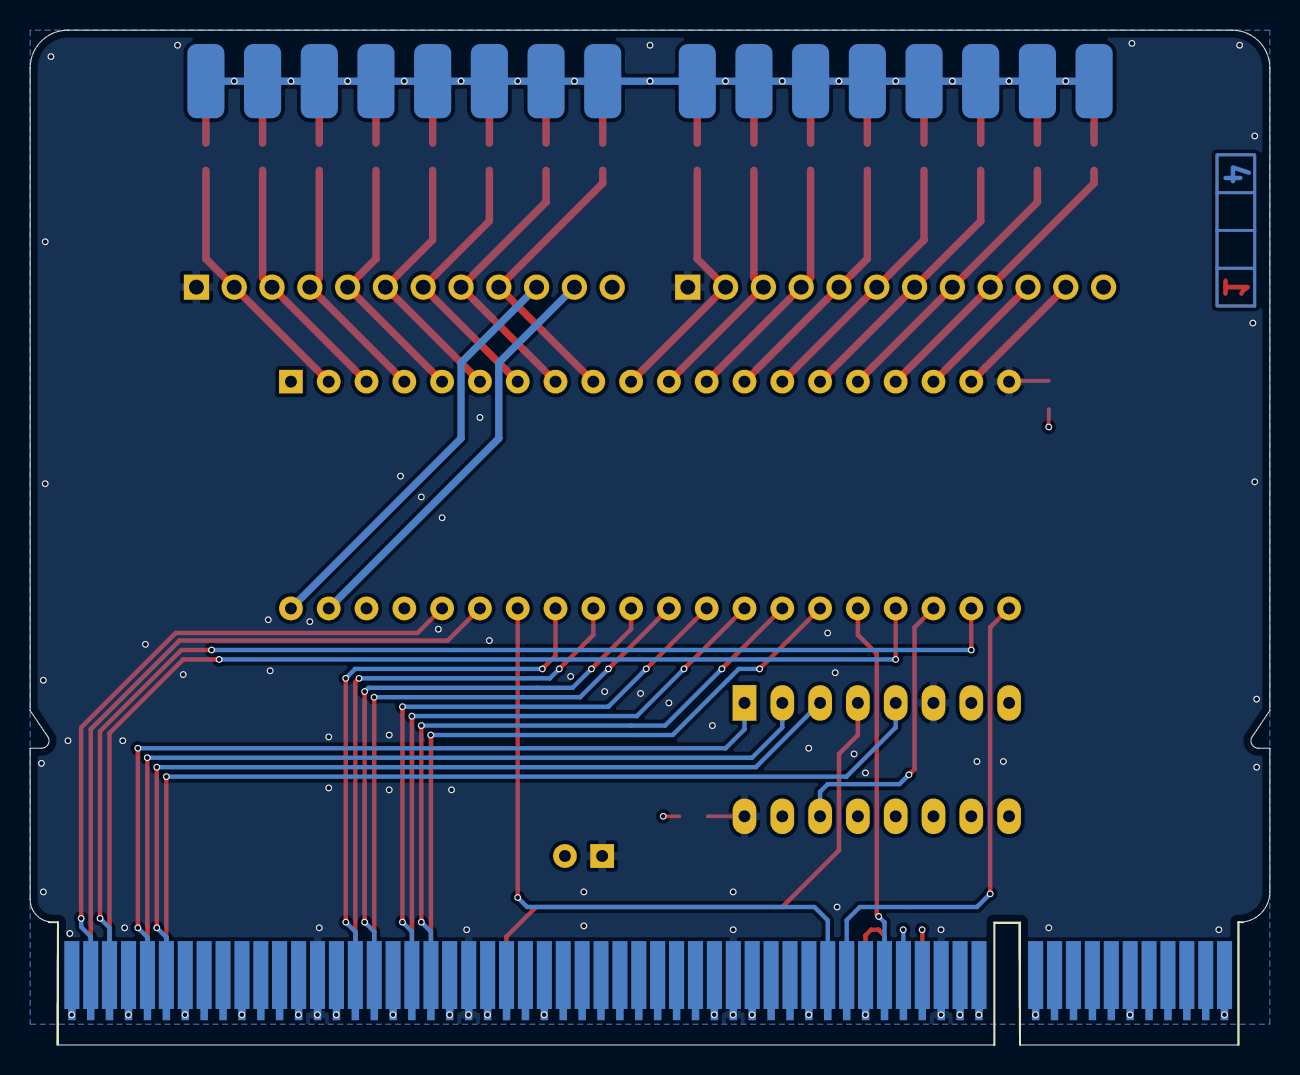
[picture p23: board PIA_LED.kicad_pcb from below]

Board: 4 copper layers, 83.3 x 68.2 mm, 41 parts (17 on the bottom side), 60 nets.

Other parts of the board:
Ref**: Val**; ladder_4

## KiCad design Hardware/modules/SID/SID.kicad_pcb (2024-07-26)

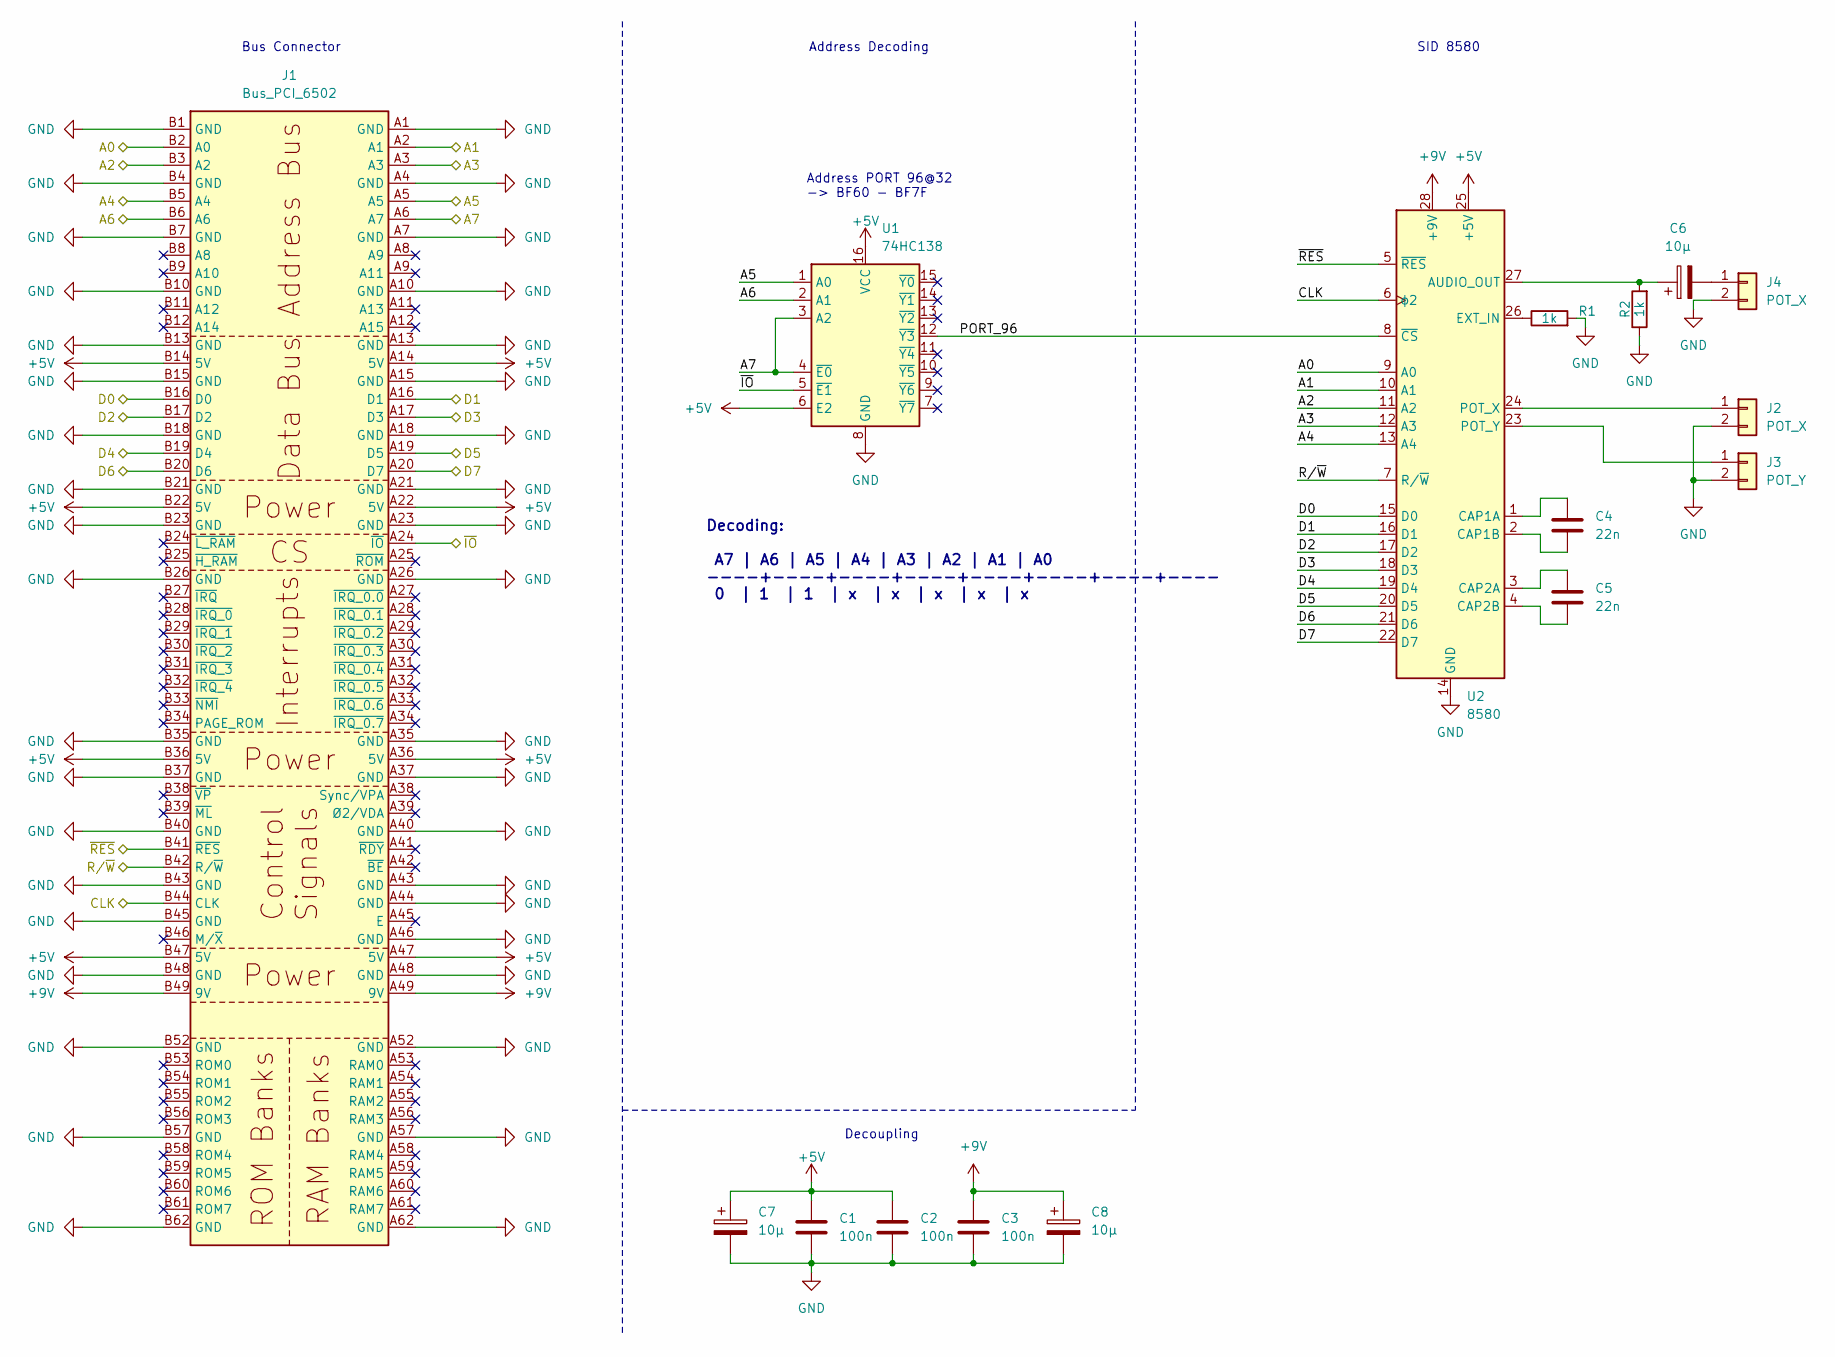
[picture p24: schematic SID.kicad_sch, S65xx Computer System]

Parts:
C1, C2, C3: 100n; C_0805_2012Metric
C4, C5: 22n; C_0805_2012Metric
C6, C7, C8: 10µ; CP_Radial_D5.0mm_P2.50mm
J1: Bus_PCI_6502; BUS_PCI
J2, J4: POT_X; PinHeader_1x02_P2.54mm_Horizontal
J3: POT_Y; PinHeader_1x02_P2.54mm_Horizontal
R1, R2: 1k; R_0805_2012Metric
U1: 74HC138; DIP-16_W7.62mm
U2: 8580; DIP-28_W15.24mm

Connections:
+5V: C1.1, C2.1, C7.1, J1.A14 (5V), J1.A22 (5V), J1.A36 (5V), J1.A47 (5V), J1.B14 (5V), J1.B22 (5V), J1.B36 (5V), J1.B47 (5V), U1.6 (E2), U1.16 (VCC), U2.25 (+5V)
+9V: C3.1, C8.1, J1.A49 (9V), J1.B49 (9V), U2.28 (+9V)
/A0: J1.B2 (A0), U2.9 (A0)
/A1: J1.A2 (A1), U2.10 (A1)
/A2: J1.B3 (A2), U2.11 (A2)
/A3: J1.A3, U2.12 (A3)
/A4: J1.B5 (A4), U2.13 (A4)
/A5: J1.A5, U1.1 (A0)
/A6: J1.B6 (A6), U1.2 (A1)
/A7: J1.A6 (A7), U1.3 (A2), U1.4 (~E0)
/CLK: J1.B44 (CLK), U2.6 (ϕ2)
/D0: J1.B16 (D0), U2.15 (D0)
/D1: J1.A16 (D1), U2.16 (D1)
/D2: J1.B17 (D2), U2.17 (D2)
/D3: J1.A17 (D3), U2.18 (D3)
/D4: J1.B19 (D4), U2.19 (D4)
/D5: J1.A19 (D5), U2.20 (D5)
/D6: J1.B20 (D6), U2.21 (D6)
/D7: J1.A20 (D7), U2.22 (D7)
/PORT_96: U1.12 (~Y3), U2.8 (~CS)
/R/~W: J1.B42 (R/~W), U2.7 (R/~W)
/~IO: J1.A24 (~IO), U1.5 (~E1)
/~RES: J1.B41 (~RES), U2.5 (~RES)
GND: C1.2, C2.2, C3.2, C7.2, C8.2, J1.A1 (GND), J1.A4 (GND), J1.A7 (GND), J1.A10 (GND), J1.A13 (GND), J1.A15 (GND), J1.A18 (GND), J1.A21 (GND), J1.A23 (GND), J1.A26 (GND), J1.A35 (GND), J1.A37 (GND), J1.A40 (GND), J1.A43 (GND), J1.A44 (GND), J1.A46 (GND), J1.A48 (GND), J1.A52 (GND), J1.A57 (GND), J1.A62 (GND), J1.B1 (GND), J1.B4 (GND), J1.B7 (GND), J1.B10 (GND), J1.B13 (GND), J1.B15 (GND), J1.B18 (GND), J1.B21 (GND), J1.B23 (GND), J1.B26 (GND), J1.B35 (GND), J1.B37 (GND), J1.B40 (GND), J1.B43 (GND), J1.B45 (GND), J1.B48 (GND), J1.B52 (GND), J1.B57 (GND), J1.B62 (GND), J2.2, J3.2, J4.2, R1.2, R2.1, U1.8 (GND), U2.14 (GND)
unnamed: J2.1, U2.24 (POT_X)
unnamed: J3.1, U2.23 (POT_Y)
unnamed: C6.2, J4.1
unnamed: C6.1, R2.2, U2.27 (AUDIO_OUT)
unnamed: C4.1, U2.1 (CAP1A)
unnamed: C4.2, U2.2 (CAP1B)
unnamed: C5.1, U2.3 (CAP2A)
unnamed: C5.2, U2.4 (CAP2B)
unnamed: R1.1, U2.26 (EXT_IN)

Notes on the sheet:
Address PORT 96@32 -> BF60 - BF7F
Decoding: A7 | A6 | A5 | A4 | A3 | A2 | A1 | A0 ----+----+----+----+----+----+----+---- 0 | 1 | 1 | x | x | x | x | x
SID 8580
Decoupling
Address Decoding
Bus Connector

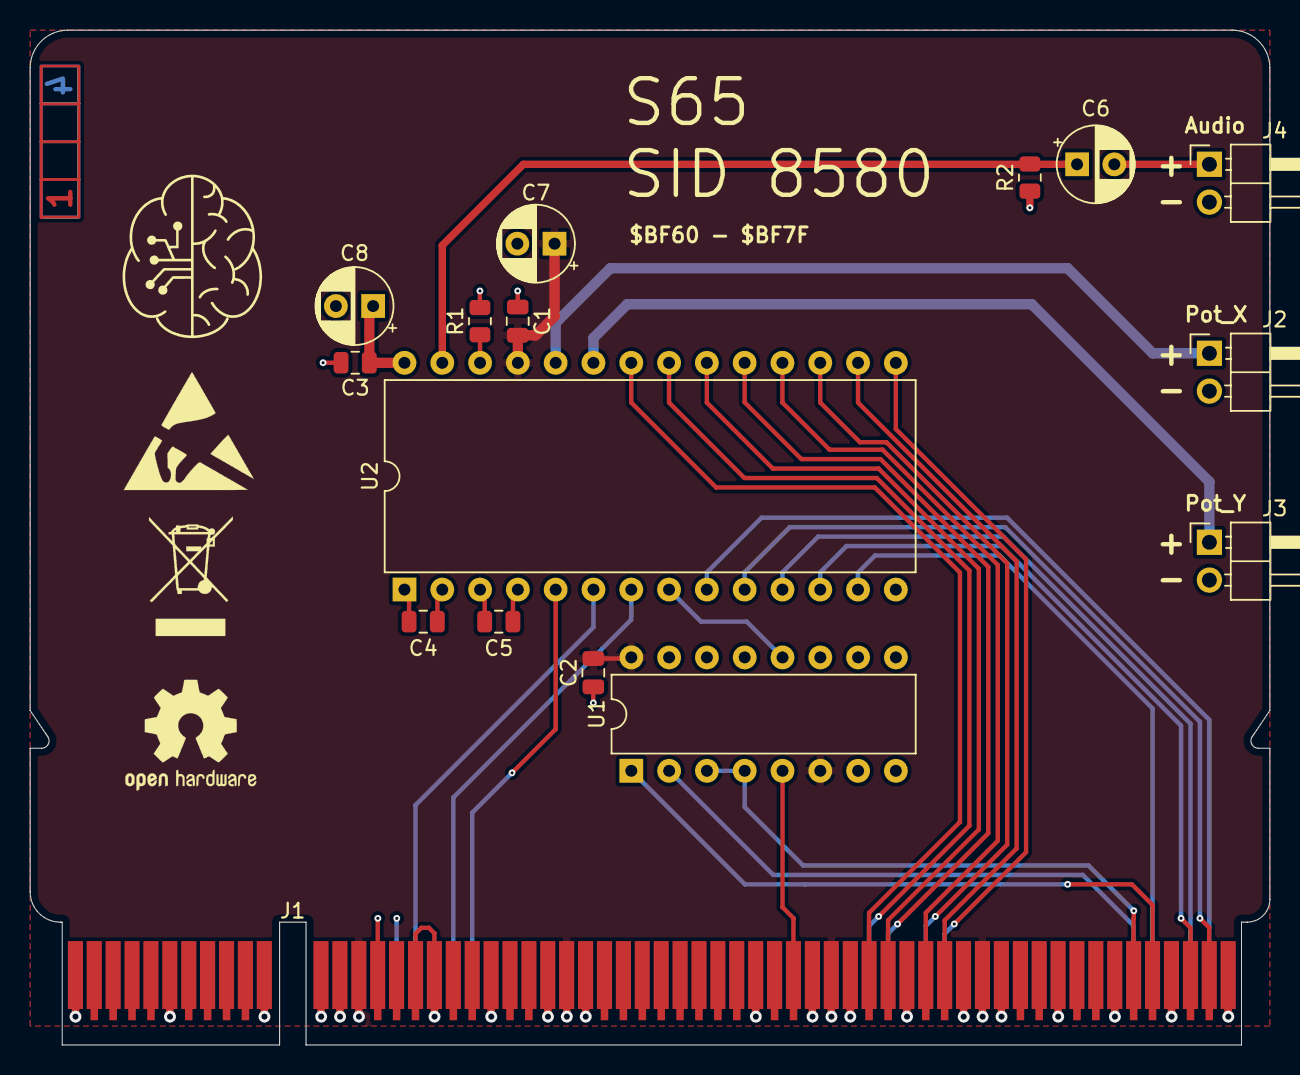
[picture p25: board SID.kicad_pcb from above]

Board: 4 copper layers, 83.3 x 68.2 mm, 17 parts (1 on the bottom side), 33 nets.

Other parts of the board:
Ref**: Val**; ladder_4

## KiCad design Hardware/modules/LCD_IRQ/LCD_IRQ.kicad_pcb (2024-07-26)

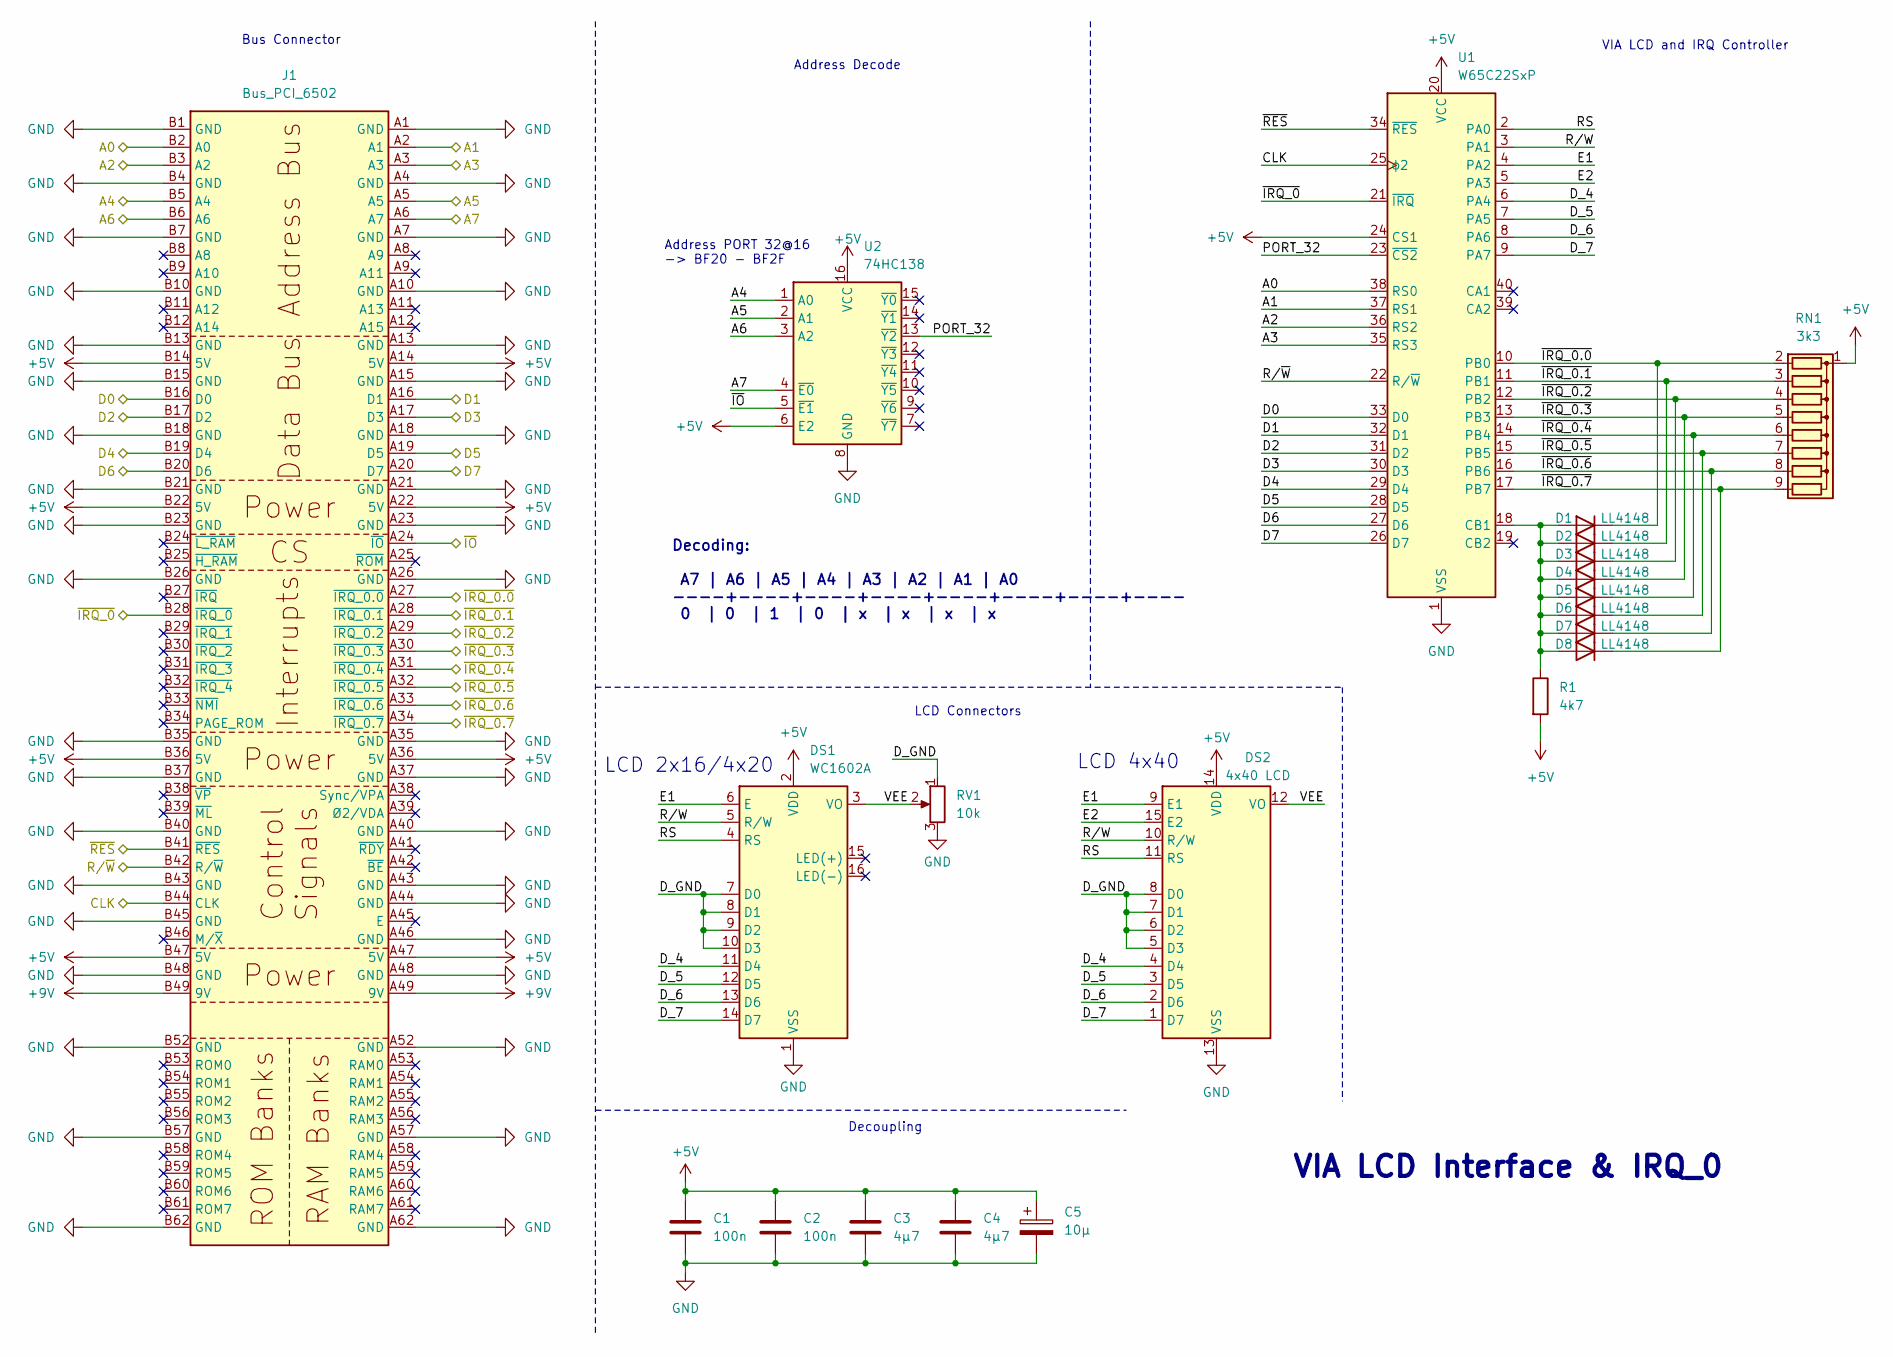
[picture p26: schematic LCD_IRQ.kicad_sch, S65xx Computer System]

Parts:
C1, C2: 100n; C_0805_2012Metric
C3, C4: 4µ7; C_0805_2012Metric
C5: 10µ; CP_Radial_D5.0mm_P2.50mm
D1, D2, D3, D4, D5, D6, D7, D8: LL4148; D_MiniMELF
DS1: WC1602A; PinHeader_1x16_P2.54mm_Vertical
DS2: 4x40 LCD; PinHeader_2x08_P2.54mm_Vertical
J1: Bus_PCI_6502; BUS_PCI
R1: 4k7; R_0805_2012Metric
RN1: 3k3; R_Array_SIP9
RV1: 10k; Potentiometer_Bourns_TC33X_Vertical
U1: W65C22SxP; DIP-40_W15.24mm
U2: 74HC138; DIP-16_W7.62mm

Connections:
+5V: C1.1, C2.1, C3.1, C4.1, C5.1, DS1.2 (VDD), DS2.14 (VDD), J1.A14 (5V), J1.A22 (5V), J1.A36 (5V), J1.A47 (5V), J1.B14 (5V), J1.B22 (5V), J1.B36 (5V), J1.B47 (5V), R1.2, RN1.1 (common), U1.20 (VCC), U1.24 (CS1), U2.6 (E2), U2.16 (VCC)
+9V: J1.A49 (9V), J1.B49 (9V)
/A0: J1.B2 (A0), U1.38 (RS0)
/A1: J1.A2 (A1), U1.37 (RS1)
/A2: J1.B3 (A2), U1.36 (RS2)
/A3: J1.A3, U1.35 (RS3)
/A4: J1.B5 (A4), U2.1 (A0)
/A5: J1.A5, U2.2 (A1)
/A6: J1.B6 (A6), U2.3 (A2)
/A7: J1.A6 (A7), U2.4 (~E0)
/CLK: J1.B44 (CLK), U1.25 (ϕ2)
/D0: J1.B16 (D0), U1.33 (D0)
/D1: J1.A16 (D1), U1.32 (D1)
/D2: J1.B17 (D2), U1.31 (D2)
/D3: J1.A17 (D3), U1.30 (D3)
/D4: J1.B19 (D4), U1.29 (D4)
/D5: J1.A19 (D5), U1.28 (D5)
/D6: J1.B20 (D6), U1.27 (D6)
/D7: J1.A20 (D7), U1.26 (D7)
/D_4: DS1.11 (D4), DS2.4 (D4), U1.6 (PA4)
/D_5: DS1.12 (D5), DS2.3 (D5), U1.7 (PA5)
/D_6: DS1.13 (D6), DS2.2 (D6), U1.8 (PA6)
/D_7: DS1.14 (D7), DS2.1 (D7), U1.9 (PA7)
/D_GND: DS1.7 (D0), DS1.8 (D1), DS1.9 (D2), DS1.10 (D3), DS2.5 (D3), DS2.6 (D2), DS2.7 (D1), DS2.8 (D0), RV1.1
/E1: DS1.6 (E), DS2.9 (E1), U1.4 (PA2)
/E2: DS2.15 (E2), U1.5 (PA3)
/PORT_32: U1.23 (~CS2), U2.13 (~Y2)
/RS: DS1.4 (RS), DS2.11 (RS), U1.2 (PA0)
/R/W: DS1.5 (R/W), DS2.10 (R/W), U1.3 (PA1)
/R/~W: J1.B42 (R/~W), U1.22 (R/~W)
/VEE: DS1.3 (VO), DS2.12 (VO), RV1.2
/~IO: J1.A24 (~IO), U2.5 (~E1)
/~IRQ_0.0: D1.1 (K), J1.A27 (~IRQ_0.0), RN1.2 (R1), U1.10 (PB0)
/~IRQ_0.1: D2.1 (K), J1.A28 (~IRQ_0.1), RN1.3 (R2), U1.11 (PB1)
/~IRQ_0.2: D3.1 (K), J1.A29 (~IRQ_0.2), RN1.4 (R3), U1.12 (PB2)
/~IRQ_0.3: D4.1 (K), J1.A30 (~IRQ_0.3), RN1.5 (R4), U1.13 (PB3)
/~IRQ_0.4: D5.1 (K), J1.A31 (~IRQ_0.4), RN1.6 (R5), U1.14 (PB4)
/~IRQ_0.5: D6.1 (K), J1.A32 (~IRQ_0.5), RN1.7 (R6), U1.15 (PB5)
/~IRQ_0.6: D7.1 (K), J1.A33 (~IRQ_0.6), RN1.8 (R7), U1.16 (PB6)
/~IRQ_0.7: D8.1 (K), J1.A34 (~IRQ_0.7), RN1.9 (R8), U1.17 (PB7)
/~IRQ_0: J1.B28 (~IRQ_0), U1.21 (~IRQ)
/~RES: J1.B41 (~RES), U1.34 (~RES)
GND: C1.2, C2.2, C3.2, C4.2, C5.2, DS1.1 (VSS), DS2.13 (VSS), J1.A1 (GND), J1.A4 (GND), J1.A7 (GND), J1.A10 (GND), J1.A13 (GND), J1.A15 (GND), J1.A18 (GND), J1.A21 (GND), J1.A23 (GND), J1.A26 (GND), J1.A35 (GND), J1.A37 (GND), J1.A40 (GND), J1.A43 (GND), J1.A44 (GND), J1.A46 (GND), J1.A48 (GND), J1.A52 (GND), J1.A57 (GND), J1.A62 (GND), J1.B1 (GND), J1.B4 (GND), J1.B7 (GND), J1.B10 (GND), J1.B13 (GND), J1.B15 (GND), J1.B18 (GND), J1.B21 (GND), J1.B23 (GND), J1.B26 (GND), J1.B35 (GND), J1.B37 (GND), J1.B40 (GND), J1.B43 (GND), J1.B45 (GND), J1.B48 (GND), J1.B52 (GND), J1.B57 (GND), J1.B62 (GND), RV1.3, U1.1 (VSS), U2.8 (GND)
unnamed: D1.2 (A), D2.2 (A), D3.2 (A), D4.2 (A), D5.2 (A), D6.2 (A), D7.2 (A), D8.2 (A), R1.1, U1.18 (CB1)

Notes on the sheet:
VIA LCD Interface & IRQ_0
LCD 4x40
VIA LCD and IRQ Controller
Decoupling
LCD 2x16/4x20
Decoding: A7 | A6 | A5 | A4 | A3 | A2 | A1 | A0 ----+----+----+----+----+----+----+---- 0 | 0 | 1 | 0 | x | x | x | x
Bus Connector
LCD Connectors
Address PORT 32@16 -> BF20 - BF2F
Address Decode


Board: 4 copper layers, 83.3 x 68.2 mm, 22 parts (1 on the bottom side), 44 nets.

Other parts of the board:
Ref**: Val**; ladder_4

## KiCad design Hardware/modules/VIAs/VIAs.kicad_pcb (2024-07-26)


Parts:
C1, C2, C3: 100n; C_0805_2012Metric
C4: 10µ; CP_Radial_D5.0mm_P2.50mm
J1: Bus_PCI_6502; BUS_PCI
J2: Port 1; Pin_Header_2x12
J3: Port 2; Pin_Header_2x12
U1, U2: W65C22SxP; DIP-40_W15.24mm
U3: 74HC138; DIP-16_W7.62mm_LongPads

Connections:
+5V: C1.1, C2.1, C3.1, C4.1, J1.A14 (5V), J1.A22 (5V), J1.A36 (5V), J1.A47 (5V), J1.B14 (5V), J1.B22 (5V), J1.B36 (5V), J1.B47 (5V), J2.1, J2.2, J3.1, J3.2, U1.20 (VCC), U1.24 (CS1), U2.20 (VCC), U2.24 (CS1), U3.6 (E2), U3.16 (VCC)
+9V: J1.A49 (9V), J1.B49 (9V)
/A0: J1.B2 (A0), U1.38 (RS0), U2.38 (RS0)
/A1: J1.A2 (A1), U1.37 (RS1), U2.37 (RS1)
/A2: J1.B3 (A2), U1.36 (RS2), U2.36 (RS2)
/A3: J1.A3, U1.35 (RS3), U2.35 (RS3)
/A4: J1.B5 (A4), U3.1 (A0)
/A5: J1.A5, U3.2 (A1)
/A6: J1.B6 (A6), U3.3 (A2)
/A7: J1.A6 (A7), U3.4 (~E0)
/CLK: J1.B44 (CLK), U1.25 (ϕ2), U2.25 (ϕ2)
/D0: J1.B16 (D0), U1.33 (D0), U2.33 (D0)
/D1: J1.A16 (D1), U1.32 (D1), U2.32 (D1)
/D2: J1.B17 (D2), U1.31 (D2), U2.31 (D2)
/D3: J1.A17 (D3), U1.30 (D3), U2.30 (D3)
/D4: J1.B19 (D4), U1.29 (D4), U2.29 (D4)
/D5: J1.A19 (D5), U1.28 (D5), U2.28 (D5)
/D6: J1.B20 (D6), U1.27 (D6), U2.27 (D6)
/D7: J1.A20 (D7), U1.26 (D7), U2.26 (D7)
/PORT_48: U1.23 (~CS2), U3.12 (~Y3)
/PORT_64: U2.23 (~CS2), U3.11 (~Y4)
/R/~W: J1.B42 (R/~W), U1.22 (R/~W), U2.22 (R/~W)
/~IO: J1.A24 (~IO), U3.5 (~E1)
/~IRQ_1: J1.B29 (~IRQ_1), U1.21 (~IRQ)
/~IRQ_2: J1.B30 (~IRQ_2), U2.21 (~IRQ)
/~RES: J1.B41 (~RES), U1.34 (~RES), U2.34 (~RES)
GND: C1.2, C2.2, C3.2, C4.2, J1.A1 (GND), J1.A4 (GND), J1.A7 (GND), J1.A10 (GND), J1.A13 (GND), J1.A15 (GND), J1.A18 (GND), J1.A21 (GND), J1.A23 (GND), J1.A26 (GND), J1.A35 (GND), J1.A37 (GND), J1.A40 (GND), J1.A43 (GND), J1.A44 (GND), J1.A46 (GND), J1.A48 (GND), J1.A52 (GND), J1.A57 (GND), J1.A62 (GND), J1.B1 (GND), J1.B4 (GND), J1.B7 (GND), J1.B10 (GND), J1.B13 (GND), J1.B15 (GND), J1.B18 (GND), J1.B21 (GND), J1.B23 (GND), J1.B26 (GND), J1.B35 (GND), J1.B37 (GND), J1.B40 (GND), J1.B43 (GND), J1.B45 (GND), J1.B48 (GND), J1.B52 (GND), J1.B57 (GND), J1.B62 (GND), J2.23, J2.24, J3.23, J3.24, U1.1 (VSS), U2.1 (VSS), U3.8 (GND)
unnamed: J2.3, U1.2 (PA0)
unnamed: J2.4, U1.10 (PB0)
unnamed: J2.5, U1.3 (PA1)
unnamed: J2.6, U1.11 (PB1)
unnamed: J2.7, U1.4 (PA2)
unnamed: J2.8, U1.12 (PB2)
unnamed: J2.9, U1.5 (PA3)
unnamed: J2.10, U1.13 (PB3)
unnamed: J2.11, U1.6 (PA4)
unnamed: J2.12, U1.14 (PB4)
unnamed: J2.13, U1.7 (PA5)
unnamed: J2.14, U1.15 (PB5)
unnamed: J2.15, U1.8 (PA6)
unnamed: J2.16, U1.16 (PB6)
unnamed: J2.17, U1.9 (PA7)
unnamed: J2.18, U1.17 (PB7)
unnamed: J2.19, U1.40 (CA1)
unnamed: J2.20, U1.18 (CB1)
unnamed: J2.21, U1.39 (CA2)
unnamed: J2.22, U1.19 (CB2)
unnamed: J3.3, U2.2 (PA0)
unnamed: J3.4, U2.10 (PB0)
unnamed: J3.5, U2.3 (PA1)
unnamed: J3.6, U2.11 (PB1)
unnamed: J3.7, U2.4 (PA2)
unnamed: J3.8, U2.12 (PB2)
unnamed: J3.9, U2.5 (PA3)
unnamed: J3.10, U2.13 (PB3)
unnamed: J3.11, U2.6 (PA4)
unnamed: J3.12, U2.14 (PB4)
unnamed: J3.13, U2.7 (PA5)
unnamed: J3.14, U2.15 (PB5)
unnamed: J3.15, U2.8 (PA6)
unnamed: J3.16, U2.16 (PB6)
unnamed: J3.17, U2.9 (PA7)
unnamed: J3.18, U2.17 (PB7)
unnamed: J3.19, U2.40 (CA1)
unnamed: J3.20, U2.18 (CB1)
unnamed: J3.21, U2.39 (CA2)
unnamed: J3.22, U2.19 (CB2)

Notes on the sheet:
Bus Interface
Address PORT 64@16 -> BF40 - BF4F
Decoding: A7 | A6 | A5 | A4 | A3 | A2 | A1 | A0 ----+----+----+----+----+----+----+---- 0 | 0 | 1 | 1 | x | x | x | x 0 | 1 | 0 | 0 | x | x | x | x
User Port 1
Address Decoding
Decoupling
VIA User Ports
User Port 2
Address PORT 48@16 -> BF30 - BF3F


Board: 4 copper layers, 83.3 x 68.2 mm, 11 parts (1 on the bottom side), 67 nets.

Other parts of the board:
Ref**: Val**; ladder_4

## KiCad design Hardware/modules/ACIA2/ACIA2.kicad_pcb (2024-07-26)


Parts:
C1, C2, C3, C4, C5, C6, C7, C8, C9, C10, C11, C12, C13, C14, C15, C16: 1µ; C_0805_2012Metric
C17, C18, C19, C20, C21, C22, C23, C24, C25: 100n; C_0805_2012Metric
C26, C27, C28, C29: 4µ7; C_0805_2012Metric
C30: 10µ; CP_Radial_D5.0mm_P2.50mm
J1: COM1/3; DSUB-9_Male_EdgeMount_P2.77mm
J2: PORT1; PinHeader_1x09_P2.54mm_Vertical
J3: COM2/4; DSUB-9_Male_EdgeMount_P2.77mm
J4: PORT2; PinHeader_1x09_P2.54mm_Vertical
J5: Bus_PCI_6502; BUS_PCI
JP1: IRQ0.0/0.2; SolderJumper-3_P2.0mm_Open_TrianglePad1.0x1.5mm_NumberLabels
JP2: IRQ0.1/0.3; SolderJumper-3_P2.0mm_Open_TrianglePad1.0x1.5mm_NumberLabels
JP3: ACIA1/3; SolderJumper-3_P2.0mm_Open_TrianglePad1.0x1.5mm_NumberLabels
JP4: ACIA2/4; SolderJumper-3_P2.0mm_Open_TrianglePad1.0x1.5mm_NumberLabels
U1, U2, U4, U5: MAX232; DIP-16_W7.62mm
U3, U6: 6551; DIP-28_W15.24mm
U7, U8: 74HC138; DIP-16_W7.62mm
X1: 1.8432MHz; Oscillator_DIP-14

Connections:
+5V: C17.1, C18.1, C19.1, C20.1, C21.1, C22.1, C23.1, C24.1, C25.1, C26.1, C27.1, C28.1, C29.1, C30.1, J2.1, J4.1, J5.A14 (5V), J5.A22 (5V), J5.A36 (5V), J5.A47 (5V), J5.B14 (5V), J5.B22 (5V), J5.B36 (5V), J5.B47 (5V), U1.16 (VCC), U2.16 (VCC), U3.2 (CS1), U3.15 (VCC), U4.16 (VCC), U5.16 (VCC), U6.2 (CS1), U6.15 (VCC), U7.6 (E2), U7.16 (VCC), U8.16 (VCC), X1.1 (EN), X1.14 (Vcc)
+9V: J5.A49 (9V), J5.B49 (9V)
/1.8432: U3.6 (XTAL1), U6.6 (XTAL1), X1.8 (OUT)
/A0: J5.B2 (A0), U3.13 (RS0), U6.13 (RS0)
/A1: J5.A2 (A1), U3.14 (RS1), U6.14 (RS1)
/A2: J5.B3 (A2), U7.1 (A0)
/A3: J5.A3, U7.2 (A1)
/A4: J5.B5 (A4), U8.1 (A0)
/A5: J5.A5, U8.2 (A1)
/A6: J5.B6 (A6), U8.6 (E2)
/A7: J5.A6 (A7), U8.5 (~E1)
/ACIA1: JP3.2 (C), U3.3 (~CS2)
/ACIA2: JP4.2 (C), U6.3 (~CS2)
/CLK: J5.B44 (CLK), U3.27 (ϕ2), U6.27 (ϕ2)
/CTS1: J2.5, U1.9 (R2OUT), U3.9 (~CTS)
/CTS2: J4.5, U4.9 (R2OUT), U6.9 (~CTS)
/CTS_1: J1.8, U1.8 (R2IN)
/CTS_2: J3.8, U4.8 (R2IN)
/D0: J5.B16 (D0), U3.18 (D0), U6.18 (D0)
/D1: J5.A16 (D1), U3.19 (D1), U6.19 (D1)
/D2: J5.B17 (D2), U3.20 (D2), U6.20 (D2)
/D3: J5.A17 (D3), U3.21 (D3), U6.21 (D3)
/D4: J5.B19 (D4), U3.22 (D4), U6.22 (D4)
/D5: J5.A19 (D5), U3.23 (D5), U6.23 (D5)
/D6: J5.B20 (D6), U3.24 (D6), U6.24 (D6)
/D7: J5.A20 (D7), U3.25 (D7), U6.25 (D7)
/DCD1: J2.8, U2.9 (R2OUT), U3.16 (~DCD)
/DCD2: J4.8, U5.9 (R2OUT), U6.16 (~DCD)
/DCD_1: J1.1, U2.8 (R2IN)
/DCD_2: J3.1, U5.8 (R2IN)
/DSR1: J2.7, U2.12 (R1OUT), U3.17 (~DSR)
/DSR2: J4.7, U5.12 (R1OUT), U6.17 (~DSR)
/DSR_1: J1.6, U2.13 (R1IN)
/DSR_2: J3.6, U5.13 (R1IN)
/DTR1: J2.6, U2.11 (T1IN), U3.11 (~DTR)
/DTR2: J4.6, U5.11 (T1IN), U6.11 (~DTR)
/DTR_1: J1.4, U2.14 (T1OUT)
/DTR_2: J3.4, U5.14 (T1OUT)
/PORT_80: U7.3 (A2), U7.4 (~E0), U7.5 (~E1), U8.14 (~Y1)
/RTS1: J2.4, U1.10 (T2IN), U3.8 (~RTS)
/RTS2: J4.4, U4.10 (T2IN), U6.8 (~RTS)
/RTS_1: J1.7, U1.7 (T2OUT)
/RTS_2: J3.7, U4.7 (T2OUT)
/RxD1: J2.3, U1.12 (R1OUT), U3.12 (RxD)
/RxD2: J4.3, U4.12 (R1OUT), U6.12 (RxD)
/RxD_1: J1.2, U1.13 (R1IN)
/RxD_2: J3.2, U4.13 (R1IN)
/R/~W: J5.B42 (R/~W), U3.28 (R/~W), U6.28 (R/~W)
/TxD1: J2.2, U1.11 (T1IN), U3.10 (TxD)
/TxD2: J4.2, U4.11 (T1IN), U6.10 (TxD)
/TxD_1: J1.3, U1.14 (T1OUT)
/TxD_2: J3.3, U4.14 (T1OUT)
/~IO: J5.A24 (~IO), U8.3 (A2), U8.4 (~E0)
/~IRQ_0.0: J5.A27 (~IRQ_0.0), JP1.1 (A)
/~IRQ_0.1: J5.A28 (~IRQ_0.1), JP2.1 (A)
/~IRQ_0.2: J5.A29 (~IRQ_0.2), JP1.3 (B)
/~IRQ_0.3: J5.A30 (~IRQ_0.3), JP2.3 (B)
/~RES: J5.B41 (~RES), U3.4 (~RES), U6.4 (~RES)
GND: C5.2, C6.2, C7.2, C8.2, C13.2, C14.2, C15.2, C16.2, C17.2, C18.2, C19.2, C20.2, C21.2, C22.2, C23.2, C24.2, C25.2, C26.2, C27.2, C28.2, C29.2, C30.2, J1.5, J2.9, J3.5, J4.9, J5.A1 (GND), J5.A4 (GND), J5.A7 (GND), J5.A10 (GND), J5.A13 (GND), J5.A15 (GND), J5.A18 (GND), J5.A21 (GND), J5.A23 (GND), J5.A26 (GND), J5.A35 (GND), J5.A37 (GND), J5.A40 (GND), J5.A43 (GND), J5.A44 (GND), J5.A46 (GND), J5.A48 (GND), J5.A52 (GND), J5.A57 (GND), J5.A62 (GND), J5.B1 (GND), J5.B4 (GND), J5.B7 (GND), J5.B10 (GND), J5.B13 (GND), J5.B15 (GND), J5.B18 (GND), J5.B21 (GND), J5.B23 (GND), J5.B26 (GND), J5.B35 (GND), J5.B37 (GND), J5.B40 (GND), J5.B43 (GND), J5.B45 (GND), J5.B48 (GND), J5.B52 (GND), J5.B57 (GND), J5.B62 (GND), U1.15 (GND), U2.15 (GND), U3.1 (VSS), U4.15 (GND), U5.15 (GND), U6.1 (VSS), U7.8 (GND), U8.8 (GND), X1.7 (GND)
unnamed: JP1.2 (C), U3.26 (~IRQ)
unnamed: JP2.2 (C), U6.26 (~IRQ)
unnamed: JP3.1 (A), U7.15 (~Y0)
unnamed: JP3.3 (B), U7.13 (~Y2)
unnamed: JP4.1 (A), U7.14 (~Y1)
unnamed: JP4.3 (B), U7.12 (~Y3)
unnamed: C1.1, U1.1 (C1+)
unnamed: C1.2, U1.3 (C1-)
unnamed: C2.1, U1.4 (C2+)
unnamed: C2.2, U1.5 (C2-)
unnamed: C5.1, U1.2 (VS+)
unnamed: C7.1, U1.6 (VS-)
unnamed: C3.1, U2.1 (C1+)
unnamed: C3.2, U2.3 (C1-)
unnamed: C4.1, U2.4 (C2+)
unnamed: C4.2, U2.5 (C2-)
unnamed: C6.1, U2.2 (VS+)
unnamed: C8.1, U2.6 (VS-)
unnamed: C9.1, U4.1 (C1+)
unnamed: C9.2, U4.3 (C1-)
unnamed: C10.1, U4.4 (C2+)
unnamed: C10.2, U4.5 (C2-)
unnamed: C13.1, U4.2 (VS+)
unnamed: C15.1, U4.6 (VS-)
unnamed: C11.1, U5.1 (C1+)
unnamed: C11.2, U5.3 (C1-)
unnamed: C12.1, U5.4 (C2+)
unnamed: C12.2, U5.5 (C2-)
unnamed: C14.1, U5.2 (VS+)
unnamed: C16.1, U5.6 (VS-)

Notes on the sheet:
Bus Connector
Solder Bridges 1-2 ACIA1: Address PORT 80@4 -> BF50 - BF53 ACIA2: Address PORT 84@4 -> BF54 - BF57
Dual ACIA UART Interface
ACIA 1
UART Clock
Decoupling
Solder Bridges 2-3 ACIA3: Address PORT 88@4 -> BF58 - BF5B ACIA4: Address PORT 92@4 -> BF5C - BF5F
ACIA 2
UART CS


Board: 4 copper layers, 83.3 x 68.2 mm, 49 parts (1 on the bottom side), 89 nets.

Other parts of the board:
Ref**: Val**; ladder_4

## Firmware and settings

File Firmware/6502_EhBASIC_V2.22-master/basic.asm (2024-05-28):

; Enhanced BASIC to assemble under 6502 simulator, $ver 2.22

; $E7E1 $E7CF $E7C6 $E7D3 $E7D1 $E7D5 $E7CF $E81E $E825

; 2.00	new revision numbers start here
; 2.01	fixed LCASE$() and UCASE$()
; 2.02	new get value routine done
; 2.03	changed RND() to galoise method
; 2.04	fixed SPC()
; 2.05	new get value routine fixed
; 2.06	changed USR() code
; 2.07	fixed STR$()
; 2.08	changed INPUT and READ to remove need for $00 start to input buffer
; 2.09	fixed RND()
; 2.10	integrated missed changes from an earlier version
; 2.20	added ELSE to IF .. THEN and fixed IF .. GOTO <statement> to cause error
; 2.21	fixed IF .. THEN RETURN to not cause error
; 2.22	fixed RND() breaking the get byte routine

; zero page use ..

LAB_WARM 		= $00		; BASIC warm start entry point ; Default $00, changed together with line 7780
Wrmjpl 		= LAB_WARM+1; BASIC warm start vector jump low byte
Wrmjph 		= LAB_WARM+2; BASIC warm start vector jump high byte

Usrjmp		= $0A		; USR function JMP address
Usrjpl		= Usrjmp+1	; USR function JMP vector low byte
Usrjph		= Usrjmp+2	; USR function JMP vector high byte
Nullct		= $0D		; nulls output after each line
TPos			= $0E		; BASIC terminal position byte
TWidth		= $0F		; BASIC terminal width byte
Iclim			= $10		; input column limit
Itempl		= $11		; temporary integer low byte
Itemph		= Itempl+1	; temporary integer high byte

nums_1		= Itempl	; number to bin/hex string convert MSB
nums_2		= nums_1+1	; number to bin/hex string convert
nums_3		= nums_1+2	; number to bin/hex string convert LSB

Srchc			= $5B		; search character
Temp3			= Srchc	; temp byte used in number routines
Scnquo		= $5C		; scan-between-quotes flag
Asrch			= Scnquo	; alt search character

XOAw_l		= Srchc	; eXclusive OR, OR and AND word low byte
XOAw_h		= Scnquo	; eXclusive OR, OR and AND word high byte

Ibptr			= $5D		; input buffer pointer
Dimcnt		= Ibptr	; # of dimensions
Tindx			= Ibptr	; token index

Defdim		= $5E		; default DIM flag
Dtypef		= $5F		; data type flag, $FF=string, $00=numeric
Oquote		= $60		; open quote flag (b7) (Flag: DATA scan; LIST quote; memory)
Gclctd		= $60		; garbage collected flag
Sufnxf		= $61		; subscript/FNX flag, 1xxx xxx = FN(0xxx xxx)
Imode			= $62		; input mode flag, $00=INPUT, $80=READ

Cflag			= $63		; comparison evaluation flag

TabSiz		= $64		; TAB step size (was input flag)

next_s		= $65		; next descriptor stack address

					; these two bytes form a word pointer to the item
					; currently on top of the descriptor stack
last_sl		= $66		; last descriptor stack address low byte
last_sh		= $67		; last descriptor stack address high byte (always $00)

des_sk		= $68		; descriptor stack start address (temp strings)

;			= $70		; End of descriptor stack

ut1_pl		= $71		; utility pointer 1 low byte
ut1_ph		= ut1_pl+1	; utility pointer 1 high byte
ut2_pl		= $73		; utility pointer 2 low byte
ut2_ph		= ut2_pl+1	; utility pointer 2 high byte

Temp_2		= ut1_pl	; temp byte for block move	

FACt_1		= $75		; FAC temp mantissa1
FACt_2		= FACt_1+1	; FAC temp mantissa2
FACt_3		= FACt_2+1	; FAC temp mantissa3

dims_l		= FACt_2	; array dimension size low byte
dims_h		= FACt_3	; array dimension size high byte

TempB			= $78		; temp page 0 byte

Smeml			= $79		; start of mem low byte		(Start-of-Basic)
Smemh			= Smeml+1	; start of mem high byte	(Start-of-Basic)
Svarl			= $7B		; start of vars low byte	(Start-of-Variables)
Svarh			= Svarl+1	; start of vars high byte	(Start-of-Variables)
Sarryl		= $7D		; var mem end low byte		(Start-of-Arrays)
Sarryh		= Sarryl+1	; var mem end high byte		(Start-of-Arrays)
Earryl		= $7F		; array mem end low byte	(End-of-Arrays)
Earryh		= Earryl+1	; array mem end high byte	(End-of-Arrays)
Sstorl		= $81		; string storage low byte	(String storage (moving down))
Sstorh		= Sstorl+1	; string storage high byte	(String storage (moving down))
Sutill		= $83		; string utility ptr low byte
Sutilh		= Sutill+1	; string utility ptr high byte
Ememl			= $85		; end of mem low byte		(Limit-of-memory)
Ememh			= Ememl+1	; end of mem high byte		(Limit-of-memory)
Clinel		= $87		; current line low byte		(Basic line number)
Clineh		= Clinel+1	; current line high byte	(Basic line number)
Blinel		= $89		; break line low byte		(Previous Basic line number)
Blineh		= Blinel+1	; break line high byte		(Previous Basic line number)

Cpntrl		= $8B		; continue pointer low byte
Cpntrh		= Cpntrl+1	; continue pointer high byte

Dlinel		= $8D		; current DATA line low byte
Dlineh		= Dlinel+1	; current DATA line high byte

Dptrl			= $8F		; DATA pointer low byte
Dptrh			= Dptrl+1	; DATA pointer high byte

Rdptrl		= $91		; read pointer low byte
Rdptrh		= Rdptrl+1	; read pointer high byte

Varnm1		= $93		; current var name 1st byte
Varnm2		= Varnm1+1	; current var name 2nd byte

Cvaral		= $95		; current var address low byte
Cvarah		= Cvaral+1	; current var address high byte

Frnxtl		= $97		; var pointer for FOR/NEXT low byte
Frnxth		= Frnxtl+1	; var pointer for FOR/NEXT high byte

Tidx1			= Frnxtl	; temp line index

Lvarpl		= Frnxtl	; let var pointer low byte
Lvarph		= Frnxth	; let var pointer high byte

prstk			= $99		; precedence stacked flag

comp_f		= $9B		; compare function flag, bits 0,1 and 2 used
					; bit 2 set if >
					; bit 1 set if =
					; bit 0 set if <

func_l		= $9C		; function pointer low byte
func_h		= func_l+1	; function pointer high byte

garb_l		= func_l	; garbage collection working pointer low byte
garb_h		= func_h	; garbage collection working pointer high byte

des_2l		= $9E		; string descriptor_2 pointer low byte
des_2h		= des_2l+1	; string descriptor_2 pointer high byte

g_step		= $A0		; garbage collect step size

Fnxjmp		= $A1		; jump vector for functions
Fnxjpl		= Fnxjmp+1	; functions jump vector low byte
Fnxjph		= Fnxjmp+2	; functions jump vector high byte

g_indx		= Fnxjpl	; garbage collect temp index

FAC2_r		= $A3		; FAC2 rounding byte

Adatal		= $A4		; array data pointer low byte
Adatah		= Adatal+1	; array data pointer high  byte

Nbendl		= Adatal	; new block end pointer low byte
Nbendh		= Adatah	; new block end pointer high  byte

Obendl		= $A6		; old block end pointer low byte
Obendh		= Obendl+1	; old block end pointer high  byte

numexp		= $A8		; string to float number exponent count
expcnt		= $A9		; string to float exponent count

numbit		= numexp	; bit count for array element calculations

numdpf		= $AA		; string to float decimal point flag
expneg		= $AB		; string to float eval exponent -ve flag

Astrtl		= numdpf	; array start pointer low byte
Astrth		= expneg	; array start pointer high  byte

Histrl		= numdpf	; highest string low byte
Histrh		= expneg	; highest string high  byte

Baslnl		= numdpf	; BASIC search line pointer low byte
Baslnh		= expneg	; BASIC search line pointer high  byte

Fvar_l		= numdpf	; find/found variable pointer low byte
Fvar_h		= expneg	; find/found variable pointer high  byte

Ostrtl		= numdpf	; old block start pointer low byte
Ostrth		= expneg	; old block start pointer high  byte
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

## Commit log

2024-05-28 initial data
    [cf.kicad_sch, clock.kicad_sch, cpu.kicad_sch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]
2024-06-03 update schematics
    [address.kicad_sch, clock.kicad_sch, cpu.kicad_sch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]
2024-06-16 make overview-schematic
    [overview_65xx.kicad_pcb, overview_65xx.kicad_sch]
2024-06-16 finalize Schematic
    [Bus_Card.kicad_pcb, Bus_Card.kicad_sch, conn.kicad_sch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]
2024-06-17 Overview Update and Backplane
    [Bus_Card.kicad_pcb, Bus_Card.kicad_sch, address.kicad_sch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]
2024-06-18 ROM and CPU Card
    [CPU.kicad_pcb, CPU.kicad_sch, ROM.kicad_pcb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]
2024-06-20 module update
    [Address_Decode.kicad_pcb, Address_Decode.kicad_sch, Bus_Card.kicad_sch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]
2024-06-23 Update Module Files and Readme
    [Address_Decode.kicad_pcb, Bank_IRQ.kicad_pcb, Bank_IRQ.kicad_sch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]
2024-06-23 update Silkscreen Bank/IRQ Card
    [Bank_IRQ.kicad_pcb]
2024-06-24 new modules and readme update
    [ACIA2.kicad_pcb, ACIA2.kicad_sch, Address_Decode.kicad_pcb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]
2024-06-25 Big Hardware Update
    [Address_Decode.kicad_pcb, Address_Decode.kicad_sch, CF.kicad_pcb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]
2024-06-25 add PCB Clamp
    [clamp-Clamp.3mf, clamp.FCStd]
2024-06-26 add LPT
    [LPT.kicad_pcb, LPT.kicad_sch]
2024-06-30 Hardware Update Add MyCPU VGA Module Beautify all Schematics minor Error corrections Readme Update
    [ACIA2.kicad_pcb, ACIA2.kicad_sch, Address_Decode.kicad_pcb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]
2024-06-30 finalize overview schematic
    [ACIA2.kicad_sch, CF.kicad_sch, IDE-Simple.kicad_sch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]
2024-06-30 Fix mirroring on High-Ram on Bank Select
    [RAM.kicad_pcb, RAM.kicad_sch, overview.kicad_sch]
2024-06-30 fix pcb outline
2024-07-01 start codebase write peripheral libraries port wozmon from Ben Eater start Kernel Development start EhBASIC porting
    [memory.cfg]
2024-07-01 add sample code for jump vector
2024-07-02 code update
    [memory.cfg]
2024-07-03 add MS BASIC to code
    [memory.cfg]
2024-07-06 update CPU design to reference WDC design
    [CPU.kicad_pcb, CPU.kicad_sch]
2024-07-06 Bus Card Update & GAL code compilation
    [segment.kicad_sch]
2024-07-07 add local ground plane on 32kHz crystal
    [Address_Decode.kicad_pcb]
2024-07-09 Chip Select Strobe Generation Bugfix
    [Address_Decode.kicad_pcb, Address_Decode.kicad_sch, Bank_IRQ.kicad_pcb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]
2024-07-10 Hardware Review Pt. 1 fix Address Decoding for Strobe Generators add bulk capacitance to every board fix wiring of Prototyping Board
    [ACIA2.kicad_pcb, ACIA2.kicad_sch, Address_Decode.kicad_pcb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]
2024-07-11 update address decode
    [Address_Decode.kicad_pcb, Address_Decode.kicad_sch]
2024-07-26 Big Review Update - Changed Copper Pours on all PCBs - Implemented errors found at review - fixed some additional errors
    [ACIA2.kicad_pcb, ACIA2.step, Address_Decode.kicad_pcb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]
